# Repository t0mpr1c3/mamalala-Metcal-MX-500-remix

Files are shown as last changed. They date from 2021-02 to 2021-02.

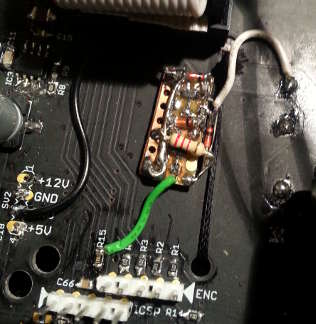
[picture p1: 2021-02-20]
doc/randomfunprojects build/build_undervoltage_lockout_PCB.jpg

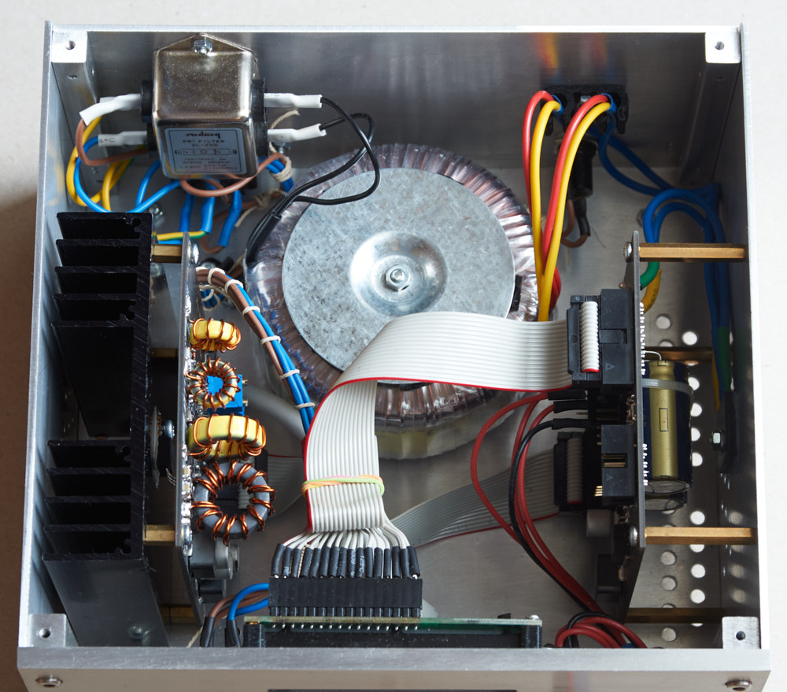
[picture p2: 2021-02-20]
doc/hww_build.jpg

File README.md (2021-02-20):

# Sources

This is the work of Christian Klippel (mamalala on EEVblog) in 2012-2013, with input from other users on the forum. This repository is an attempt to collate information punlished in the main project thread, https://www.eevblog.com/forum/projects/diy-metcal-13-56-mhz-rf-supply/

I haven't attempted to build the project myself and have no specialist knowledge to bring to bear.

## richard.cs build

http://randomfunprojects.co.uk/metcal.html

### Comment in post #374

"Whilst you could use the original gerbers I would suggest a few changes:
1) Add in pads for the extra 56 pF capacitor.
2) Put some thermal relief in. I've found a lot of areas where something that carries no real current (DC or RF) like a logic pulldown is unsolderable with a small iron because one end is hard-down onto a large area of ground plane.
3) Consider swapping the LCD pinout to the standard one.
4) A little bit of BOM rationalisation would be nice. For example the Aux supply capacitor for the switcher (can't remember the number now) is currently the only 1206 10nF in the design and could have been the same as the 10nF 0805's scattered everywhere.
5) Depending on your skill with surface mount soldering the pads might benefit from tweaking slightly - they're perfect for reflow but a little tight for hand work."

"The mounting holes on the board are 3.2 mm, this is a perfectly normal size for clearance M3 but I suspect that for many people with an electronics-only background getting four tapped holes in position to within perhaps 0.2 mm will be difficult, and being tapped the heatsink holes can't simply be opened out a little bigger. Might I suggest that loose-fitting 3.5 mm or even 4 mm holes might be preferable on a future board revision."

### Comment in post #375

"The mounting holes on the board are 3.2 mm, this is a perfectly normal size for clearance M3 but I suspect that for many people with an electronics-only background getting four tapped holes in position to within perhaps 0.2 mm will be difficult, and being tapped the heatsink holes can't simply be opened out a little bigger. Might I suggest that loose-fitting 3.5 mm or even 4 mm holes might be preferable on a future board revision."

### Comment in post #512

"I built [my toroids] as per the schematic and notes, with 1uH, 1uH, 400n, 11 turns on a T80, 14 turns on a T50 and then 10 on the next T50. It works well and I've made no attempt to optimise it further."

## See also

- https://hackaday.com/2019/06/16/homemade-magic-makes-the-metcal-go/
- https://habr.com/en/post/451246/
- https://github.com/SergeyMax/SolderingStation
- https://www.eevblog.com/forum/reviews/metcal-mx-5200-and-mx-5000-firmware-and-data-eeprom-information/

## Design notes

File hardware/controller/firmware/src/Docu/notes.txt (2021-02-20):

idle voltage around 14V
boost/limit around +/- 3.5V change in idle voltage

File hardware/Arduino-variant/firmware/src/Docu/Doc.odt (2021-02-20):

The encoder button has various uses:

- Single click

- Long push

- Double click

- Single click followed by a long push

Single click:

Press encoder button down and then quickly release it

Long push:

Press and hold down encoder button for a second or two

Double click:

Press encoder button, quickly release it, then immediately press and release it again

Click + longpush:

Press encoder button, quickly release it, then press it again and hold down for 1 or 2 seconds

During normal operation the LCD shows a status-icon in the top-left corner, depicting the current power setting (Off, Normal, Limit, Boost) and a „still alive“ animation in the bottom row of the icon. Next to the icon is the bargraph showing the current output power. In the bottom line the current power-manager state is shown, or alternatively the currently active power manager configuration name. Toggle between the two by double-clicking the encoder button.

Status Icons:

Power Output Off

Normal Power Output

Limited Power Output

Boosted Power Output

When in automatic mode, i.e. with the power manager enabled, the following actions are possible:

- Single click used to turn on/off

- When turned on, Click-Longpush to enter sleep mode when

- When in sleep mode, rotate the encoder to force wake up

- Longpush to enter the main menu

When in manual mode, i.e. with the power manager disabled, the following actions are possible:

- Single click to turn on/off, memorizes last power level for on

- Turn encoder left/right to change output power mode (Off, Normal, Limit, Boost)

- Longpush to enter main menu

Main Menu

From the default info-display after power-up, the main can be entered by a longpush on the encoder button. Push & hold the button until the main menu is displayed. Once in the main menu, rotate the encoder to select the desired option. These are:

- Main Setup: Global system configuration

- Edit Config: Edit the power-manager configuration

- Save Config: Save the edited power manager configuration

- Load Config: Load and activate one of the stored power manager configurations

- Show Version: Display the firmware name and version

- Reset: Reboot the firmware

To select a menu item, simply click the encoder button once.

To exit the main menu, simply do a longpush on the encoder button again until you are back to the main info display.

Main Setup

This configures the basic, global parameters of the system. Changes made here are immediately active. Rotate the encoder to cycle through the available options. These are:

- Language: Select the language used for display and serial output. Currently English and German are implemented.

- Baudrate: Set the baudrate of the serial interface. Only the baudrate can be selected, the other parameters for the serial port are always 8,N,1. Note: When realtime logging is used, a low baudrate will cause a very slow response of the system, so select a suitably high baudrate in this case.

- Logger: What info messages to log through the serial port, realtime parameter logging

- Startup PM Conf.: Select which power-manager configuration to automatically load at system power-up from the configuration storage.

When selection an option, the currently active one is displayed by default. To cahnge the option, simply rotate the encoder to select the desired one, and then do a single click which does the actual selection and in turn brings you back to the options overview. The Logger options are different since these are multiple-choice. A * in front of the selected option shows that it is active. Do a single click to toggle between active and non-active. Rotate the encoder to select a different sub-option. Do a longpush to get back to the options overview. The Startup PM Conf. option will show you the textual name of the selected config-set from memory.

When exiting the Main Setup options the selected settings will automatically be saved to the internal EEPROM.

Edit Config

This allows to edit the runtime parameters of the power-manager. Selecting this option will first bring up which parameterset to edit. The choices are:

- Current Config: The currently active configuration

- From Default Cfg: Start with a configuration filled with default parameters

- One of the eight stored configurations. The name of that config will be shown in the bottom line of the LCD, while the memory slot it used is displayed in the upper-right corner of the LCD, from #0 to #7

A single click will select the configuration and starts the editor, a longpush will exit and go back to the main menu. The options are grouped into sub-items as follows:

- Startup Mode:

- Auto, On – Auto, Off – Manual, On – Manual, Off

- Heatup Mode

- Normal Power – Power Limit – Power Boost

- Heatup End Cond.

- Timed – Pwr Lvl Thresh.

- Heatup End Param

- HeatupLim, Time – HeatupLim, PwrTh – HeatupBst, Time – HeatupBst, PwrTh

- Idle Parameters

- Idle Threshold – Enter Sleep Time

- Sleep Options

- Sleep Mode - Auto-Powerdown

- Sleep Mode Param

- Light Sleep Time – Light Slp Thresh – Sleep Threshold – Auto-Off Time

- Wakeup Mode

- Normal Power – Power Bosst

- Wakeup End Cond.

- Timed – Pwr Lvl Thresh.

- Wakeup End Param

- WakeupBst, Time – WakeupBst, PwrTh

- Normal Backlight

- Constant – Pulsing - Flashing

- Sleep Backlight

- Constant – Pulsing - Flashing

- Auto Off Backl.

- Constant – Pulsing - Flashing

- Const. BL Param.

- Const. BL. Level

- Pulse BL Param.

- Pulse Level Low – Pulse Level High – Pulse Speed

- Flash BL Param

- Flash Level Low – Flash Level High – Flash On-Time – Flash Off-Time

- Config Name

- Actual name of the currently edited parameter set

To select a group, click the selection. Then select which parameter to change and click again. Adjust the parameter as wanted and click or longpush. This will bring you back to the parameter selection of that group. To go back to the group selection then, do a longpush. To exit the editor, do another longpush.

The name editor is slightly different. When starting to edit the name, the current name will be shown in the top line on the LCD. In the bottom line a – is shown. Rotate the encoder to move that marker under the character that is to be changed. Then click the encoder button. The marker will change to a ^ and thus indicate that the character is to be changed. Rotate the encoder to change it. Click to get back to the – marker to select another character. The name-editing can be aborted by a longpush. To save the edited name, use a clickpush instead.

In case of multi-option (i.e. The Sleep Options), a single click will enable/disable the option, a longpush will go back to the option selection menu.

The option-groups and their parameters have the following purposes/meanings:

- Startup Mode: Select in which mode to start-up the unit after power-on/reset

- Auto, On: Automatic power management is enabled, turned on after power-up

- Auto, Off: Automatic power management is enabled, turned off after power-up

- Manual, On: Manual control mode, turned on after power-up

- Manual, Off: Manual control mode, turned off after power-up

- Heatup Mode: Select what power level to use for initial heatup

- Normal Power: Use normal power output during heatup

- Power Limit: Use limited power output during heatup

- Power Boost: Use boosted power output during heatup

- Heatup End Cond.: Select the condition to end initial heatup, only for boost/limit heatup modes

- Timed: End heatup phase after a given number of seconds

- Pwr Lvl Thresh.: End heatup phase when power output fall below a given threshold

- Heatup End Param: Times (in seconds) and power levels for the limit/boost heatup modes

- HeatupLim, Time: Time after which to end the limited power heatup phase

- HeatupLim, PwrTh: Power level below which to end the limited power heatup phase

- HeatupBst, Time: Time after which to end the bossted power heatup phase

- HeatupBst, PwrTh: Power level below which to end the boosted power heatup phase

- Idle Parameters: Defines threshold between idle/heating mode, and a time after which to enter sleep mode

- Idle Threshold: Rise in output power after which to go from idle to heating mode

- Enter Sleep Time: Time in seconds of idling after which to go to sleep mode, if enabled

- Sleep Options: Enable/disable the sleep-mode and automatic power-down

- Sleep Mode: Enable/disable the entering of the sleep mode when idling too long

- Auto-Powerdown: Enable/disable the auto-powerdown mode when sleeping too long

- Sleep Mode Param: Define times and thresholds for the sleep mode

- Light Sleep Time: Time spent in ininital sleep mode, to accomodate power level change from idle mode

- Light Slp Thresh: Rise threshold in output power when in inital sleep mode, wakes up when exceeded

- Sleep Threshold: Rise threshold in output power for normal sleep mode, wakes up when exceeded

- Auto-Off Time: Time spent sleeping after which to automatically power down

- Wakeup Mode: Power output setting when waking up from sleep mode

- Normal Power: Wake up using normal power output

- Power Boost: Wake up with boosted output power (quicker thermal recovery)

- Wakeup End Cond.: Condition to end boosted output power wakeup, when enabled

- Timed: End boosted power wakeup after given time in seconds

- Pwr Lvl Thresh.: End boosted output power wakeup when power consumption falls below a given threshold

- Wakeup End Param: Time (in seconds) and power level for the boost wakeup modes

- WakeupBst, Time: Time after which to end the bossted power wakeup phase

- WakeupBst, PwrTh: Power level below which to end the boosted power wakeup phase

- Normal Backlight: Which LCD Backlight mode to use to signal normal operation (heatup, idle, etc.)

- Constant: Fixed brightness level

- Pulsing: Fade brightness level up/down continously

- Flashing: Flash brightness level

- Sleep Backlight: Which LCD Backlight mode to use to signal sleep mode

- Constant: Fixed brightness level

- Pulsing: Fade brightness level up/down continously

- Flashing: Flash brightness level

- Auto Off Backl.: Which LCD Backlight mode to use to signal automatic power down mode

- Constant: Fixed brightness level

- Pulsing: Fade brightness level up/down continously

- Flashing: Flash brightness level

- Const. BL Param.: Brightness level used for constant backlight

- Const. BL. Level

- Pulse BL Param.: Brightness levels and time/speed for pulsating backlight

- Pulse Level Low: Minimum brightness to fade from/to

- Pulse Level High: Maximum brightness to fade from/to

- Pulse Speed: Speed to fade between low/high brightness, bigger=slower and smaller=faster

- Flash BL Param: Brightness levels and times/speeds for flashing backlight

- Flash Level Low: Minimum brightness to quickly fade to

- Flash Level High: Maximum brightness to flash to

- Flash On-Time: Time spent for high-brightness flash-fade

- Flash Off-Time: Time spent to wait for next flash

- Config Name

- Actual name of the currently edited parameter set

Save Config

This allows to save the edited runtime parameters of the power-manager. Selecting this option will first bring up which parameterset to load. The choices are:

- Make Active: Activate the currently edited configuration, i.e. ese it. No actual saving is done.

- One of the eight stored configurations. The name of the config currently present in the selected slot will be shown in the bottom line of the LCD, while the memory slot it used is displayed in the upper-right corner of the LCD, from #0 to #7. Click to select that slot and overwrite it with the edited config.

Load Config

This allows to load and activate the runtime parameters of the power-manager. Selecting this option will first bring up which parameterset to load. The choices are:

- From Edit Config: The currently edited configuration

- One of the eight stored configurations. The name of that config will be shown in the bottom line of the LCD, while the memory slot it used is displayed in the upper-right corner of the LCD, from #0 to #7

Show Version

This will show the firmware name and version. Simply rotate the encoder to exit from that display.

Reset

Do a reboot of the firmware, same result as if power-cycling the unit.

The config editor always allows to edit all options, no matter if they depend on another config option or not. For example, the Heatup End Cond and Heatup End Param are only used when either the limited power or the boosted power heatup mode is selected, but never used when the normal heatup mode is chosen.

When editing a config, it is just that: an edited config. It does not become active unless it is either saved to EEPROM and then loaded, or when explicitely chosen to activate it.

EEPROM storage uses CRC checksums to verify that all is OK. When an invalid CRC is encountered, the config or parameter set will be replaced with a default one. This applies to both, the main config as well as any of the power manager configurations. When flashing the firmware into the µC it will create default configurations at the first power up. This is also shown in the ourput on the serial interface. Default serial port speed is 115200 Baud.

The encoder handling has a very crude „dynamic“ in it. The faster it is turned, the bigger the steps in which it changes. This allows to adjust a large value range without needing to rotate it for ages. However, it is just that: crude. So donÄt expect too much from it.

Button handling is not perfect either. Sometimes it just misses something. Especially when extensive realtime logging is enabled on the serial port. That extensive logging then also affects the rotary encoder.

The menu handling and config editor „run“ in the background, depending on which one is active. That means that the power manager is always running. So you can happily edit something or stay in the menu without affecting the automatic power management.

Multi-language support in the firmware is implemented by using a big array of pointers to strings, one for each language. The active array is the selected by the language manager, depending on the chosen language. To access a string, a simple tr() macro is defined which takes the string-index and returns the pointer to that string in program memory.

The actual strings are defined in strings_EN for English, and strings_DE for German. In language_strings.h is a long list of defined string names that represent the index to a string. The order of these #defines must be the same as the strings in the actual strings_* files. In the same include files the number of languages etc. are defined at the top.

To add a new language simply create a new strings_* file, use the strings_EN as a template here. Replace all the strings to whatever language you want. Change the NUM_LANGUAGES accordingly, and add a new „#define LANG_*“ to languages_strings.h. Then extend the language_entries[] struct in languages_strings.c, and add the „#include strings_*“ for the new language to it. That should be all....

All the menu and config option stuff is defined in their own structs, so that the main handlers stay the same while allowing to easily add new menus, sub-menus, options, etc.

Not much documentation in the source code yet. After all, this is just V00.01, that is, the first somewhat usable revision.

There are quite some leftovers in the files from the development. Stuff has changed, but some code not deleted or #defines removed. In short: it's quite a mess right now. Also, some names used for functions, variables and defines are not that good and should change.

Have fun!

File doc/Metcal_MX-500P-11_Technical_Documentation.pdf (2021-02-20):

# METCAL MX-500P-11 TECHNICAL DOCUMENTATION

This documentation was carefully reverse engineered from several actual MX-500P units, and although it has been meticulously triple checked, it may contain errors and omissions so use it at your own risk. It is provided solely for the purpose of helping you satisfy your personal curiosity about how a Metcal MX-500P works, and you must never use it for any other purpose, especially not for any commercial or business purpose, and certainly not as an aide to experimenting with or performing work on MX-500P units, as it is inadequate for such unintended use. Reproduction is strictly forbidden.

MECHANICAL DESCRIPTION:

The small plastic cover at the two RF output connectors is held in place by it's two plastic hooked clips which descend into the aluminum housing at the top and bottom. Beneath this plastic cover are two hex nuts that bolt the RF connectors to the aluminum housing. The RF connectors are soldered directly into the circuit board. On the rear of the MX-500P are four deeply recessed T15 tamper proof Torx screws which hold the two halves of the aluminum casting together. Loosening the single screw in the upper-middle back of the MX-500P by a few turns releases the internal heat sink which is attached to the circuit board. The internal heat sink couples heat into the MX-500P aluminum case from where it can dissipate into the ambient air. Good thermal coupling between the internal heat sink and the case is aided by a thin coating of white thermal compound. The circuit board inside the MX-500P is fastened down by six internal screws, four of which are rather large because they also hold down the line transformer. The tiny grub screw on the upper right hand side of the MX500 controls the Auto Sleep feature and should not be tightened past the point where it gently activates the switch. Note that it can be dangerous to power up an MX-500P unit that has been taken apart or that has been reassembled by anyone other than an trained Metcal service technician.

DESCRIPTION OF FUNCTION:

The MX-500P Power Unit provides RF energy at 13.560MHz to the Soldering Tip Cartridge, which contains an induction heater consisting of an 18 turn AWG33 wire coil wound around a 0.11" diameter by 0.5" long slug. The slug is composed of a copper core, clad in a thin magnetic alloy having a curie point equal to the desired soldering tip temperature. The magnetic alloy absorbs RF energy from the coil, causing the slug to heat up until the curie temperature is reached. At this point absorption stops and heating ceases, because the RF energy is now reflected back to the power unit by the copper core.

The On/Off switch atop the power unit controls the 18V power supply U8, which runs all the supervisory circuits. When the 18V supply is off, Q6 turns off thereby causing Q7 to turn on and disable the RF generator.

Q5 and Q8 control a small DC bias voltage out to the soldering hand piece, so that U2a can sense an intermittent or disconnected hand piece cable, in which case the yellow LED DS2 will light and U2b will latch Q7 on, thereby disabling the RF generator until the On/Off switch is cycled.

U5a senses small changes in RF generator output power to the soldering hand piece. If no changes are detected for half an hour then sleep mode timer U6 times out causing U7 to latch Q11 on, thereby disabling the RF generator until the On/Off switch is cycled. This functionality can be disabled by backing out the tiny grub screw in the upper right side of the unit.

If thermal switch TS1 detects an over temperature condition inside the power unit then Q9 will turn on and disable the RF generator until the temperature drops back down to normal.

If Forward Power at T3 and C33 exceeds reasonable limits due to a fault in the power unit circuitry, then Q19 will turn on and disable the RF generator until Forward Power returns to acceptable levels.

U5b monitors the supervisory circuits and lights green LED DS1 if everything is OK, in which case Q12 will be on, enabling U4 to power up the RF generator.

U1 provides a 13.560MHz square wave out to class C driver stage Q3, which in turn drives the class C final output stage Q4, providing RF power to the soldering hand piece. Note that Q3 is unusual in that it has an input capacitance of only 55pF and a gate threshold voltage of only 1.6V.

Diodes D8 and D9 sense the RF voltage level coming out of the RF generator, providing negative feedback to switching power supply U4 Q1 Q2, which powers the final RF output stage Q4 of the RF generator.

J1 provides a DC voltage which is proportional to the power being delivered to the hand piece. It can be connected to an analog meter movement or other measuring instrument.

TRIMPOT DESCRIPTIONS:

RV2 adjusts the RF-Output-Power delivered to the hand piece; if this adjustment is incorrect then the voltage at C8 will likely not correspond to the values given elsewhere in this document.

RV1 sets the Forward-Power-Fault safety shutdown circuit trip point; if this adjustment is incorrect then the voltage at C16 will likely not correspond to the values given elsewhere in this document.

RV3 calibrates the signal out to any Meter connected at J4; the signal at J4 is not normally used so it is hard to imagine how this adjustment could have any impact upon the operation of the unit.

Calibration is well beyond the scope of this document and must not be attempted by anyone other than a qualified Metcal service technician.

MEASUREMENTS FROM SOME GOOD WORKING UNITS:

Whenever unit is plugged into the AC line:
Voltage at C2 will measure approximately 26 VDC
Voltage at C6 will measure approximately 53 VDC Whenever the power switch is on and unit is plugged in:
U8 pin 3 will measure 18 VDC
U7 pin 14 will measure 12 VDC
Whenever a hand piece is connected and the green LED is lit: U4 pin 4 will measure 1.3 VDC
U4 pin 5 will measure 0.0 VDC
If the green LED is extinguished but the unit is plugged in: U4 pin 5 will measure 26 VDC
Whenever the hand piece is idling hot in the stand:
Voltage at C8 will measure between 17 and 18 VDC Voltage at C3 will measure between 14 and 15 VDC
Voltage at C16 will measure approximately minus 1.2 VDC
U1 pin 14 will measure approximately 4.8 VDC
U1 pin 4 will have a 13.56 Mhz waveform approximately 2.8 Vpp When the soldering hand piece is heating up from a cold start:
Voltage at C8 may temporarily rise as high as 21 VDC
Voltage at C16 may temporarily rise as high as minus 0.22 VDC When the hot hand piece is touched to something cold:
U5 Pin 1 will pulse high momentarily
Characteristics of a cold MX Soldering Tip Cartridge:
Inductance at 1kHz is somewhere around 2.8 uH DC resistance is fairly close to 0.21 ohms

ADDITIONAL INFORMATION:

For specifications and descriptions of operator controls and lights, please consult you Metcal Users Manual and the 1999 Metcal product catalog which can be found on the Internet via Google as of this writing.

US Patent Number 4626767 contains a wealth of additional technical information. US Patents are available for free on the Internet from various sources such as http://www.freepatentsonline.com/

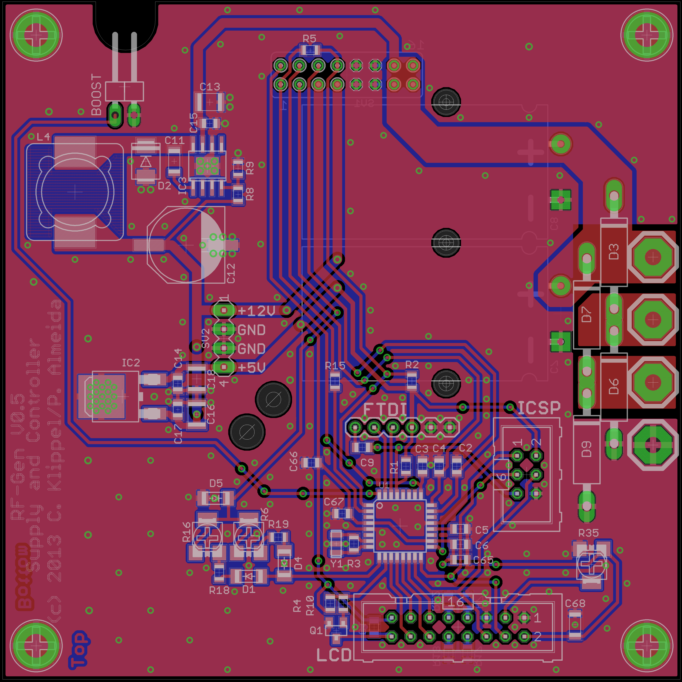
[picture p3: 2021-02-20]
hardware/Arduino-variant/ControllerBoard.png

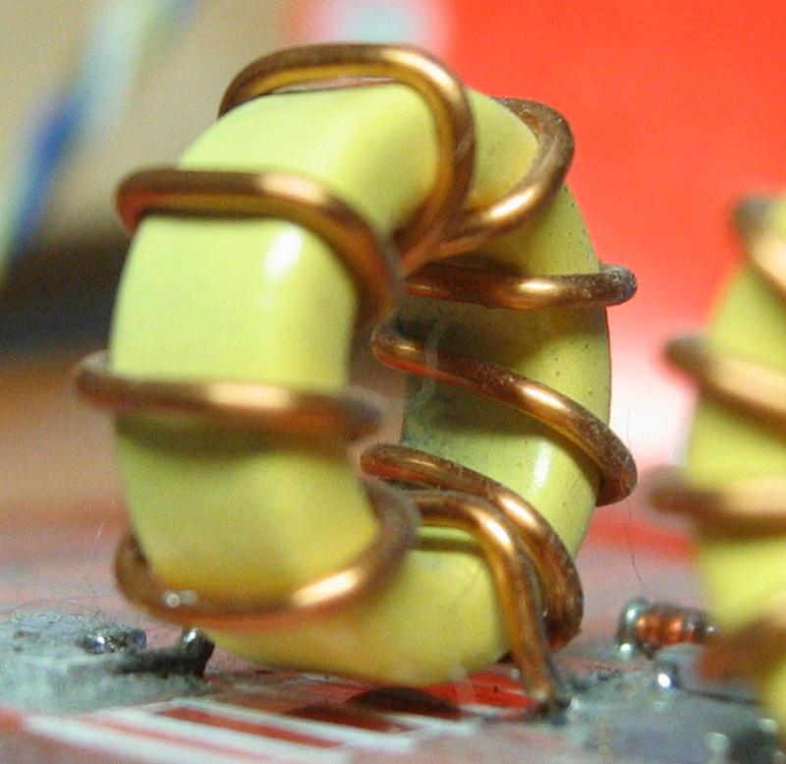
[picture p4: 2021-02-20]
doc/coil_4.jpg

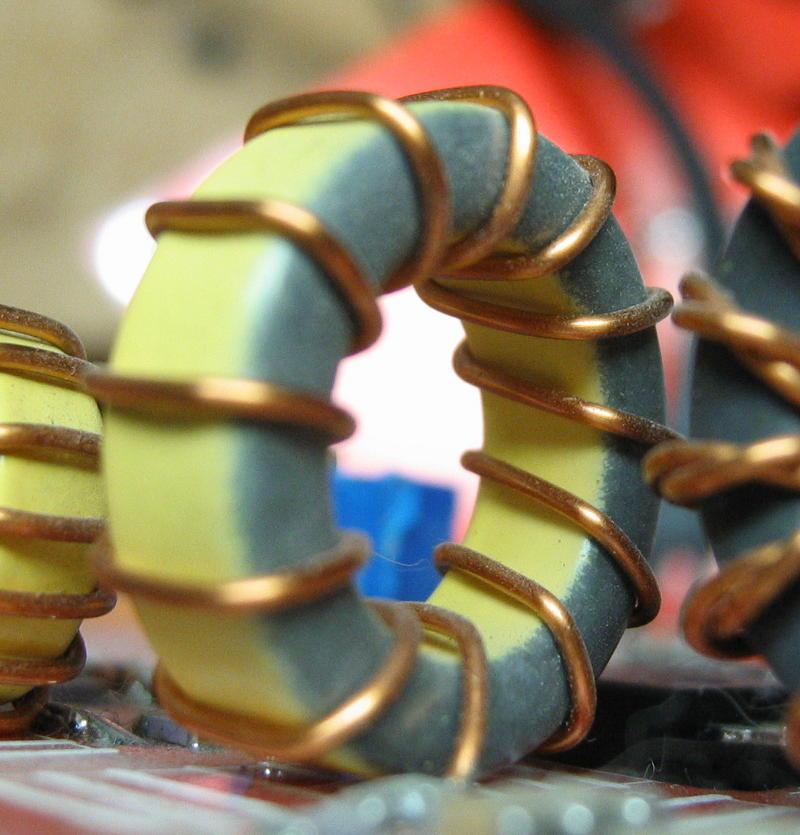
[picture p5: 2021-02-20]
doc/coil_2.jpg

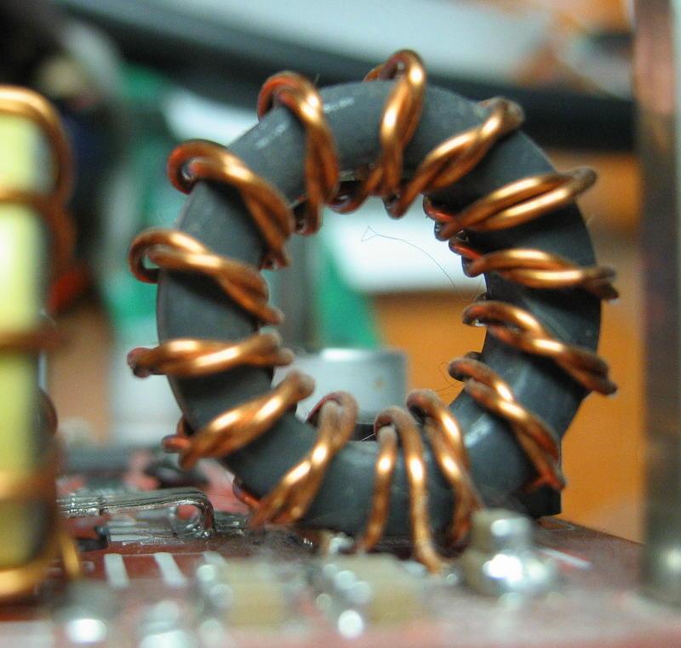
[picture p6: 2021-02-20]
doc/coil_1.jpg

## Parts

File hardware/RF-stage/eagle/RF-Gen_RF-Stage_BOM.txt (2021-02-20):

Partlist exported from C:/Users/Tom/Documents/hack/metcal/MX-500P/mamalala-Metcal-MX-500-remix/hardware/RF-stage/eagle/RF-Gen_RF-Stage.sch at 2/20/2021 10:58 AM

Part  Value                     Device              Package          Description       
C1    100µ/50V                  C-POL-EU-AL_100_108 CAP_AL_100_108                     
C2    10µ/50V                   C-EU-1210           C_1210_REFLOW                      
C3    10µ/50V                   C-EU-1210           C_1210_REFLOW                      
C4    10µ/50V                   C-EU-1210           C_1210_REFLOW                      
C5    100n                      C-EU-0805           C_0805_REFLOW                      
C6    10n                       C-EU-1206           C_1206_REFLOW                      
C7    100µ/50V                  C-POL-EU-AL_100_108 CAP_AL_100_108                     
C8    100µ/50V                  C-POL-EU-AL_100_108 CAP_AL_100_108                     
C9    100n                      C-EU-0805           C_0805_REFLOW                      
C10   100n                      C-EU-0805           C_0805_REFLOW                      
C11   100n                      C-EU-0805           C_0805_REFLOW                      
C12   4µ7                       C-EU-1206           C_1206_REFLOW                      
C13   100n                      C-EU-1206           C_1206_REFLOW                      
C14   47n                       C-EU-1206           C_1206_REFLOW                      
C15   47n                       C-EU-1206           C_1206_REFLOW                      
C16   47n                       C-EU-1206           C_1206_REFLOW                      
C17   47n                       C-EU-1206           C_1206_REFLOW                      
C18   47n                       C-EU-1206           C_1206_REFLOW                      
C19   47n                       C-EU-1206           C_1206_REFLOW                      
C20   22p                       C-EU-1206           C_1206_REFLOW                      
C21   22p                       C-EU-1206           C_1206_REFLOW                      
C22   56p                       C-EU-1206           C_1206_REFLOW                      
C23   56p                       C-EU-1206           C_1206_REFLOW                      
C24   56p                       C-EU-1206           C_1206_REFLOW                      
C25   56p                       C-EU-1206           C_1206_REFLOW                      
C26   56p                       C-EU-1206           C_1206_REFLOW                      
C27   56p                       C-EU-1206           C_1206_REFLOW                      
C28   56p                       C-EU-1206           C_1206_REFLOW                      
C29   56p                       C-EU-1206           C_1206_REFLOW                      
C30   56p                       C-EU-1206           C_1206_REFLOW                      
C31   56p                       C-EU-1206           C_1206_REFLOW                      
C32   56p                       C-EU-1206           C_1206_REFLOW                      
C33   100n                      C-EU-0805           C_0805_REFLOW                      
C34   100n                      C-EU-0805           C_0805_REFLOW                      
C35   10n                       C-EU-0805           C_0805_REFLOW                      
C36   10n                       C-EU-0805           C_0805_REFLOW                      
C37   56p                       C-EU-1206           C_1206_REFLOW                      
C38   56P                       C-EU-1206           C_1206_REFLOW                      
C39   56p                       C-EU-1206           C_1206_REFLOW                      
C40   N/A                       C-EU-0805           C_0805_REFLOW                      
C41   2µ2                       C-EU-1206           C_1206_REFLOW                      
C42   100n                      C-EU-0805           C_0805_REFLOW                      
C43   100n                      C-EU-0805           C_0805_REFLOW                      
C44   22p                       C-EU-0805           C_0805_REFLOW                      
C45   22p                       C-EU-0805           C_0805_REFLOW                      
C46   100n                      C-EU-1206           C_1206_REFLOW                      
C47   100n                      C-EU-1206           C_1206_REFLOW                      
C48   56p                       C-EU-1206           C_1206_REFLOW                      
D1                              DIODE-SMB           SMB              RECTIFIER DIODES  
D2    1N4148                    DIODE-LL-34         LL-34            RECTIFIER DIODES  
D3    1N4148                    DIODE-LL-34         LL-34            RECTIFIER DIODES  
D4    Z5.6                      DIODE-LL-34         LL-34            RECTIFIER DIODES  
D5    Z5.6                      DIODE-LL-34         LL-34            RECTIFIER DIODES  
D6    1N4148                    DIODE-LL-34         LL-34            RECTIFIER DIODES  
D7    1N4148                    DIODE-LL-34         LL-34            RECTIFIER DIODES  
D8    Z5.6                      DIODE-LL-34         LL-34            RECTIFIER DIODES  
D9    z5.6                      DIODE-LL-34         LL-34            RECTIFIER DIODES  
D10   Z5.6                      DIODE-LL-34         LL-34            RECTIFIER DIODES  
FET1  IRF510                    NFETTO22_INPCB      TO220_INPCB                        
IC1   LM22676TJ7A               LM22676TJ7A         TO-263_THIN                        
IC2   ISL55110TSSOP-8           ISL55110TSSOP-8     TSSOP-8                            
IC3   TLV2374                   TLV2374SOIC-14      SOIC14                             
IC4   SN74LVC1GX04DBV           SN74LVC1GX04DBV     DBV-R-PDSO-G6                      
L1    22µ                       L-EU-SSR1260        SSR1260                            
L2    22µ                       L-EU-SSR1260        SSR1260                            
L3    11 turns T80-6            L-EU-T80_U          L_T80_U                            
L4    14 turns T50-6            L-EU-T50_U          L_T50_U                            
L5    8 turns T50-6             L-EU-T50_U2         L_T50_U2                           
L6    47µ                       L-EU-2424           L_2424                             
PAD1                            SMDPAD5X4           SMDPAD_5X4                         
PAD2                            SMDPAD5X4           SMDPAD_5X4                         
Q1    2N7002                    BSS123              SOT23            N-CHANNEL MOS FET 
Q2    2N7002                    BSS123              SOT23            N-CHANNEL MOS FET 
R1    22k                       R-EU-0805           R_0805_REFLOW                      
R2    18k                       R-EU-0805           R_0805_REFLOW                      
R3    2k2                       R-EU-0805           R_0805_REFLOW                      
R4    1k                        R-EU-0805           R_0805_REFLOW                      
R5    2M                        R-EU-0805           R_0805_REFLOW                      
R6    1k                        R-EU-0805           R_0805_REFLOW                      
R7    22k                       R-EU-0805           R_0805_REFLOW                      
R8    4R7                       R-EU-1206           R_1206_REFLOW                      
R9    4R7                       R-EU-1206           R_1206_REFLOW                      
R10   22k                       R-EU-0805           R_0805_REFLOW                      
R11   100                       R-EU-0805           R_0805_REFLOW                      
R12   100                       R-EU-0805           R_0805_REFLOW                      
R13   100                       R-EU-0805           R_0805_REFLOW                      
R14   100                       R-EU-0805           R_0805_REFLOW                      
R15   22k                       R-EU-0805           R_0805_REFLOW                      
R16   100                       R-EU-0805           R_0805_REFLOW                      
R17   22k                       R-EU-0805           R_0805_REFLOW                      
R18   82k                       R-EU-0805           R_0805_REFLOW                      
R19   5k                        TRIM_EU-S64Y_SMD    S64Y_SMD         POTENTIOMETER     
R20   100                       R-EU-0805           R_0805_REFLOW                      
R21   1k                        R-EU-0805           R_0805_REFLOW                      
R22   22k                       R-EU-0805           R_0805_REFLOW                      
R23   22k                       R-EU-0805           R_0805_REFLOW                      
R24   100                       R-EU-0805           R_0805_REFLOW                      
R25   5k                        TRIM_EU-S64Y_SMD    S64Y_SMD         POTENTIOMETER     
R26   4k7                       R-EU-0805           R_0805_REFLOW                      
R27   1k                        R-EU-0805           R_0805_REFLOW                      
R28   1k                        R-EU-0805           R_0805_REFLOW                      
R29   1k                        R-EU-0805           R_0805_REFLOW                      
R30   1k                        R-EU-0805           R_0805_REFLOW                      
R31   22k                       R-EU-0805           R_0805_REFLOW                      
R32   2k                        TRIM_EU-3364W       3364W            POTENTIOMETER     
R33   100                       R-EU-0805           R_0805_REFLOW                      
R34   100                       R-EU-0805           R_0805_REFLOW                      
SV1                             MA08-2SMD           MA08-2-SMD       PIN HEADER        
U$1   MOUNTPADM3_WASHER         MOUNTPADM3_WASHER   PAD_M3_WASHER                      
U$2   MOUNTPADM3_WASHER         MOUNTPADM3_WASHER   PAD_M3_WASHER                      
U$3   MOUNTPADM3_WASHER         MOUNTPADM3_WASHER   PAD_M3_WASHER                      
U$4   MOUNTPADM3_WASHER         MOUNTPADM3_WASHER   PAD_M3_WASHER                      
XFMR1 2 x 13 o. 14 Turn FT82-61 XFMR_1_1_CTT80_U    XFMR_T80_U                         
XTAL1 13.56MHz                  XTALSMD_5.0X3.2     XTAL_SMD_5.0X3.2

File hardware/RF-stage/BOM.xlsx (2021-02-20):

QUANTITY | PART | VALUE | PACKAGE | MFG N° (EXAMPLE) There are other and maybe cheaper alternatives | HARD TO GET BITS INCL.
 | RESISTORS 1%
7 | R4,R6,R21,R27,R28,R29,R30 | 1K | 0805 | CRCW08051K00FKEA
8 | R1,R7,R10,R15,R17,R22,R23,R31 | 22K | 0805 | CRCW080522K0FKEA
8 | R11,R12,R13,R14,R16,R20,R33,R34 | 100R | 0805 | CRCW0805100RFKEA
1 | R24 | 200R | 0805 | CRCW0805200RFKEA
1 | R5 | 2M | 0805 | CRCW08052M00FKEA
1 | R3 | 2.2K | 0805 | CRCW08052K20FKEA
2 | R8,R9 | 4.7R | 1206 | CRCW12064R70JNEA
1 | R26 | 4.7K | 0805 | CRCW08054K70FKEA
1 | R2 | 18K | 0805 | CRCW080518K0FKEA
1 | R18 | 160K | 0805 | CRCW0805160KFKEA
 | TRIMPOTS
1 | R32 | 2K | TRIM3364W | 3364W-1-202E
1 | R19, R25 (omitted) | 5K | (Bend pins to fit SMD) 3296Y | 3296Y-1-502LF
 | NOT INSTALLED
1 | Non-inductive dummy load (use with big heatsink) | 50R | TO-247 | MHP100500F
QUANTITY | DIODE
4 | D2,D3,D6,D7 | LL4148 | SOD80 / LL34 | FDLL4148
1 | D1 | 5A | DO214AA / SMB | CDBB560-HF
5 | D4,D5,D8,D9,D10 | 5.6V | SOD-80C / LL34 | BZV55-C5V6
QUANTITY | CAPACITORS
3 | C1,C7,C8 | 100uF/50V or 63V | PANASONIC FK | EEEFK1H101P or EEEFK1J101P
3 | C2,C3,C4 | 10uF/50V | 1210 X7R | GRM32ER71H106KA12L
8 | C5,C9,C10,C11,C33,C34,C42,C43 | 100nF | 0805 X7R | GRM21BR71H104KA01L
1 | C6 | 10nF | 1206 X7R | GRJ31BR72J103KWJ1L
1 | C12 | 4.7uF/25V | 1206 X7R | GRM31CR71E475KA88L
3 | C13,C46,C47 | 100nF/250V | 1206 X7R | GRM31CR72E104KW03L
6 | C14,C15,C16,C17,C18,C19 | 47nF | 1206 X7R | GRJ31CR72E473KWJ3L
1 | C20 (omitted),C21 | 22pF | 1206 C0G/NP0 | GRM31A5C2J220JW01D
14 | C22,C23,C24,C25,C26,C27,C28,C29,C30 (omitted),C31,C32,C37,C38,C39,C48 | 56pF | 1206 C0G/NP0 | GRM3165C1H560JZ01D
2 | C35,C36 | 10nF | 0805 C0G/NP0 | GRM2195C1H103JA01D
1 | C41 | 2.2uF/16V | 1206 X7R | GRM31MR71C225KA35L
2 | C44,C45 | 10pF | 0805 C0G/NP0 | GRM21A5C2E100JW01D
 | NOT INSTALLED
 | C40 | - | - | -
QUANTITY | INDUCTORS
2 | L1,L2 | 22uH | DR127 | DR127-220-R
1 | L3 -DIY- | 11 turns | T 80-6 | AMIDON T 80-6 | X
1 | L4 -DIY- | 14 turns | T 50-6 | AMIDON T50-6 | X
1 | L5 -DIY- | 8 turns | T 50-6 | AMIDON T50-6 | X
1 | L6 | 47uH | PIS2408 | FASTRON L-PIS2408 | X
1 | XFMR1 DIY |  | FT 82-61 | Ferritring 5961000601 | X
 | Copper Enamel Wire |  |  | sold by 10m Spool if needed
QUANTITY | IC /ACTIVE
1 | IC1 | LM22676 | TO-263 DDPAK | LM22676TJE-ADJ/NOPB
1 | IC2 | ISL55110 | TSSOP-8 | ISL55110IVZ
1 | IC3 | TLV2374 | SOIC-14 | TLV2374ID
1 | IC4 | SN74LVC1GX04DBV | SOT-23 | SN74LVC1GX04DBVT
1 | XTAL1 | 13.56MHZ OSC | 7B | 7B-13.560MEEQ-T
2 | Q1,Q2 | 2N7002 | SOT-23-3 | 2N7002,215
QUANTITY | MECHANICAL
1 | SV1 | 2x8 | 0.1" pitch pin header

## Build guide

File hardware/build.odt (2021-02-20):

13.56 MHz RF Power Supply

RF Generator Board

Notes, Assembly and Adjustment

© 2012 Christian Klippel <c.klippel@gmx.de>

This document describes the basic operation principle, assembly steps and required adjustment for a 13.56 MHz RF power supply. Such a supply can be used with soldering handpieces, cartridges, tweezers, etc. from the OKI/Metcal and Thermaltronics soldering systems designed to operate at this frequency.

With this project you should be able to build your own power supply unit for these systems. Please note that this is not a direct copy of the existing power supply designs. While it is based on the same principles, the design itself was created from ground up by myself. There are quite some differences in this design compared to the existing ones, mainly in an attempt to hopefully make the whole circuitry simpler.

The supply is basically a RF generator at a fixed frequency, 13.56 MHz in this case, where the feedback loop of the DC supply of the final stage includes the actual RF output/reflected measurement to ensure that the output stage is not damaged when a mismatch occurs. The cartridges work by RF induction into a special alloy which, at a fixed temperature, loses its ability to have energy induced magnetically. When that Curie point is reached, a mismatch of the RF load (the cartridge) will occur, and most of the RF energy is reflected back into the output stage. With fixed-power output stages this would lead to the destruction of the output stage. However, in these units here the RF power is reduced as soon as the mismatch occurs to prevent this from happening.

IC1 on this board is the DC/DC buck converter that provides the DC voltage to the output stage. Between L4 and L5 the peak voltage of the RF signal is picked up by the circuitry on the lower-left on page 3 of the circuit diagrams. That circuitry is just a simple peak detector. It's output is buffered by one of IC3's op amps, and then fed back, through a series resistor, into the feedback pin of IC1. So what this combination does is effectively trying to provide a constant peak voltage at the junction between L4 and L5. At power up pretty much all the RF energy is consumed by the tip cartridge. Once it reaches its design temperature, that RF energy is reflected back into the supply. This will lead to an increasing peak voltage seen by the peak-detector. In the end, the output of the op amp rises as well, causing a higher voltage at IC1's feedback input. This in turn will cause IC1 to decrease its output voltage, and thus the voltage seen by the peak detector: the feedback loop is complete.

Another important part of the circuit is the detection of the tip cartridge. This is accomplished by the circuitry in the lower-right of page 3 of the circuit diagrams. The tip cartridge has a very low DC resistance. This part of the circuit sends a small DC current through the tip, which will effectively pull the gate of Q1 to ground, thus Q1 is switched off. If the tip is removed Q1 is now switched on by the pullup resistor R21. Basically, L6 blocks the RF AC voltage, whereas R20 and C41 provide a low-pass filter that adds a tiny delay to debounce the resulting signal.

A useful extra in this circuit is the SWR bridge. This provides a detection of the forward and reflected RF energies which in turn can be evaluated by external circuitry to provide finer control of the system. However, this part is somewhat optional and not required for the basic operation of the supply.

The circuit is designed to include some failsafe and protection points. For example, I included a bunch of 5.6 V Zener diodes. Normally they would do nothing. But in case something fails, they should provide some basic protection against overvoltage at the inputs of the parts on the 5 V rail, mainly the op amp and whatever circuitry follows that.

Another difference to the original units is the driver part of the output FET. While the originals use another FET as driver, I decided to use the ISL55110 FET driver chip from Intersil. It is a tiny chip, designed to drive a FET with sufficient current, at high frequencies. I also created a much smaller and simpler oscillator circuit. The originals, at least the older ones, use a full 7404 chip and crystal to form the oscillator. However, there is the SN74LVC1GX04 available from Texas Instruments, which is basically just a '04, but condensed down into a small SOT23-6 package and internally wired for operation as an oscillator. To this I connected a small 5.0 x 3.2 mm SMD 13.56 MHz crystal, plus the required feedback and series resistor, as well as the load capacitances for the crystal.

Generally I tried to use parts that are easy to solder by hand. Passives are not smaller than 0805, for example. As for the part values and tolerances, for some parts it is important to have the exact same specs that I will give in the part lists, for others there is quite some leeway. For example the voltage rating of the bulk capacitor at the input of the DC/DC buck converter. This obviously depends on what you decide to use to power it with. I used 50 V spec'd stuff there, just to be on the safe side. But you are welcome to change that, if you must.

I will mark the important parts with a *, to indicate that the specs of those parts are important. I will also add some commentary about what parts are optional. For example, if you don't need the SWR bridge stuff, you can leave those parts out. However, in that case a low-Ohm resistor should be connected between the op amp inputs and GND instead of the small capacitors.

Considering this, I will not give a single, complete part list for the whole board. Instead I will provide partial part lists with each section that will be explained in the instructions below, together with some comments on those parts.

Alright then, so let's start building it!

To build and test this circuit you need a few tools at hand. One is a suitable power supply. The values I give in this document refer to +30 V for the DC input to the buck converter. You also need a +5 V and +12 V supply for the op amp, oscillator and FET driver.

There are a few toroids that need to be wound with magnet wire (that is, enameled copper wire) between 0.7 and 0.8 mm in diameter.

A normal multimeter should be OK to successfully build this circuit, but having a scope available surely won't hurt in case something does not work out as expected.

You also need a 50 Ohm, non-inductive dummy load. It should be a 50 Watts type, one of these things that is used by radio hams, for example. This we will use to provide a basic load to the buck converter during assembly, as well as load to the RF output later on.

You need a decent soldering iron with tips suitable for SMD soldering, plus a larger hoof tip to solder the buck regulator thermal pad to the PCB.

And of course the usual tools like pliers, etc.

The first section to assemble is the DC/DC buck converter section as seen in the graphic below.

Part # | Value | Size | Notes
C1, C7, C8 | 100µ / 50V* | 10.0 x 10.8 mm | Low-ESR electrolytic
C2, C3, C4 | 10µ / 50V* | SMD 1210 | X7R, at least C2, others optional
C5 | 100n / 50V* | SMD 0805 | X7R
C6 | 10n / 50V* | SMD 1206 | X7R
R1 | 22K | SMD 0805 | Pulldown, 22K minimum
R2 | 18K* | SMD 0805 | 1% or better
R3 | 2K2* | SMD 0805 | 1% or better
R4 | 2K* | SMD 0805
R11 | 4K7 | SMD 0805 | Can be omitted, see text
R32 | 2K* | SMD 3364W | Or any other that fits footprint
D1 | 60V / 5A | SMB | Schottky, for example SK56B R4
L1, L2 | 22µ*, 4A min. | SSR1260 | Or any other that fits footprint SSR1260-220M from Bourns for example
IC1 | LM22676* | TJ7A | TO-263 thin package
SV1 | 2 x 8* | 0.1” | SMD pin- or socket-header, see text

In this section we have one optional part. This is resistor R11. If you want your controller to be able to temporarily increase or decrease the output voltage, you need to install this resistor here. The value of 4.7 K is just a rough guide, it actually depends on how you control this functionality later on (that is, what voltage levels you inject and how).

What gender the connector SV1 has is up to you. You can use a pin header here and plug a flat-ribbon cable plus connector onto it, or you can use a socket header and plug in the controlling board into that, in case you want to stack the two boards. The reason to use a socket header (female) in case of a stacked configuration is because you can get long THT pin headers, but not long socket headers.

The very first part to solder in is IC1, using a large hoof tip. This is because we need to solder its thermal pad as well, and other parts would be in the way otherwise. First we need to fill the vias on the PCB in the area that the thermal pad should be soldered to. Also we tin the thermal pad of IC1 a bit. Here are two images of the areas of interest, one before and one after tinning/filling:

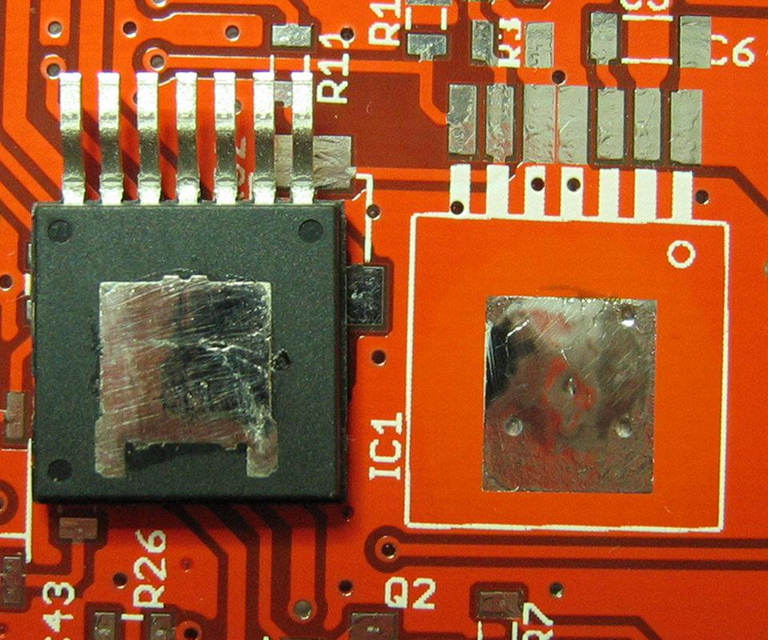
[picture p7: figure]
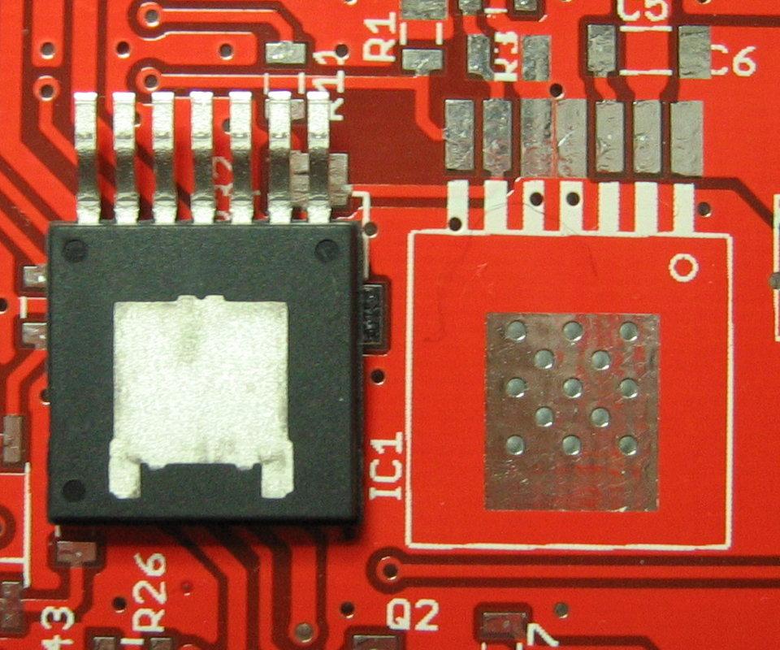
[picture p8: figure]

Add enough solder to the area on the PCB so that it slightly bulges, then clean off the flux residues on the PCB and the chip. The idea here is that when the chip is placed, it will be slightly tilted when from the side. We also tack-on the chip at the two outermost pins:

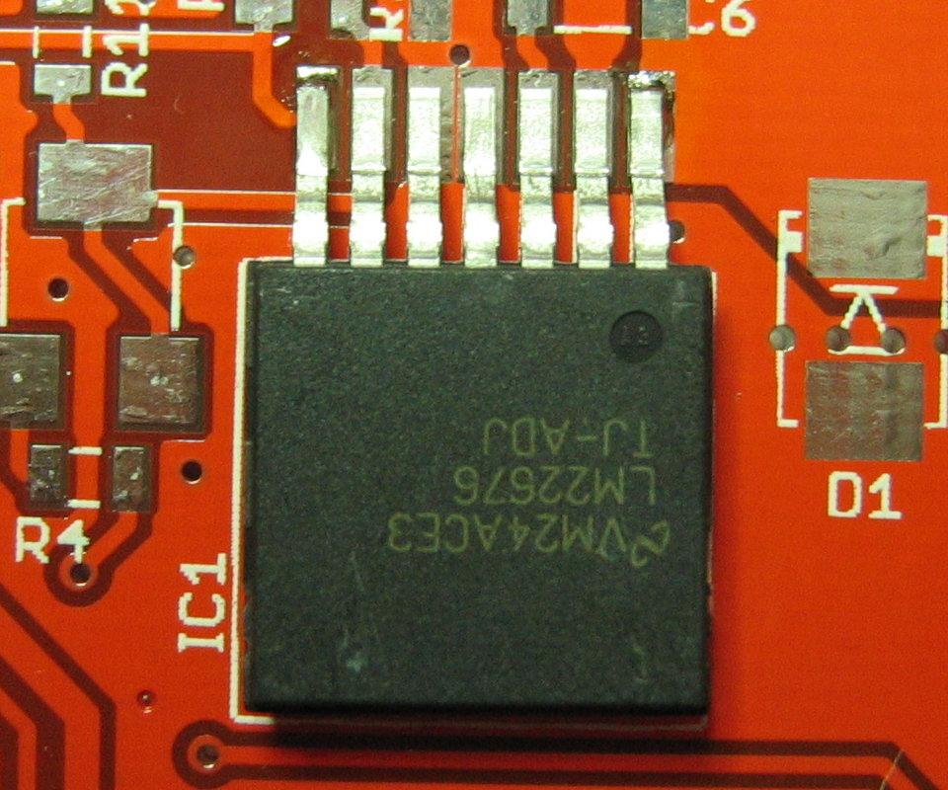
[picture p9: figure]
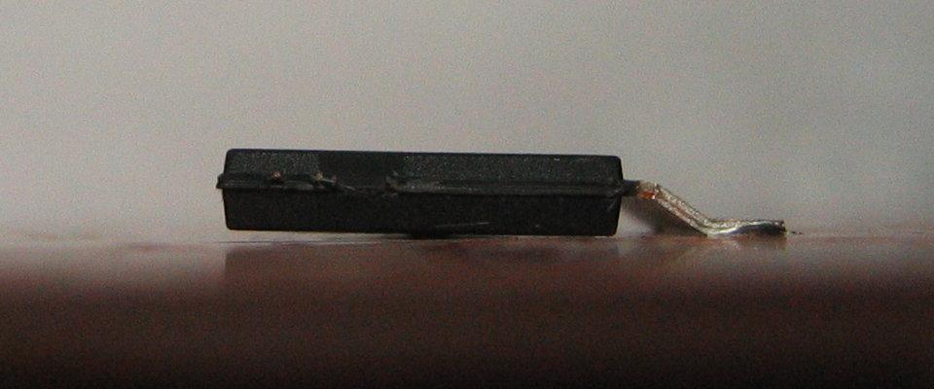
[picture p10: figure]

Now flip over the PCB, preferably on a hard surface. Add plenty of solder to the area where the thermal vias are. Now apply pressure with your fingers, above and below that area. With the other hand put the hoof tip into the tinned area. Move the tip around over the whole area for a while. The idea is that the vias, filled with solder, will conduct the heat to the other side and melt the solder there. Due to the applied pressure it will then solder IC1 flat on, giving a good thermal contact between its thermal pad and the copper of the PCB. Check from the side that the chip is really flat on. If needed repeat the procedure. Ance all is OK, use some desolder wick and remove excess solder, so that you have virtually no bulging in that area anymore. Then clean off the flux residues, flip the board over again and solder on the remaining pins:

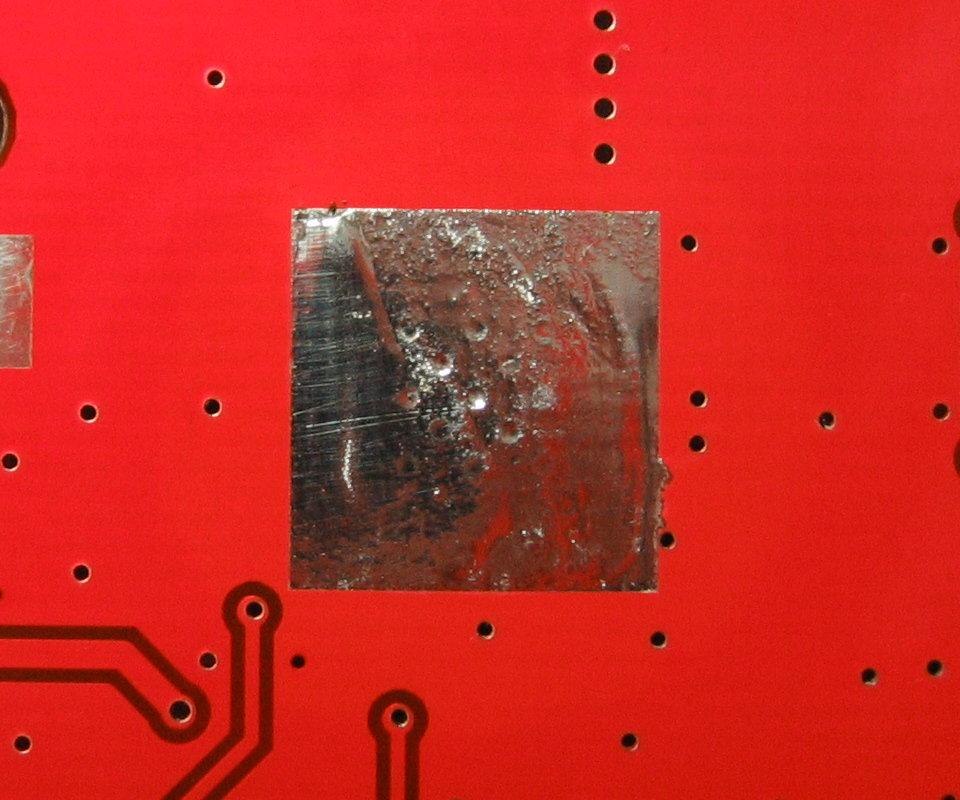
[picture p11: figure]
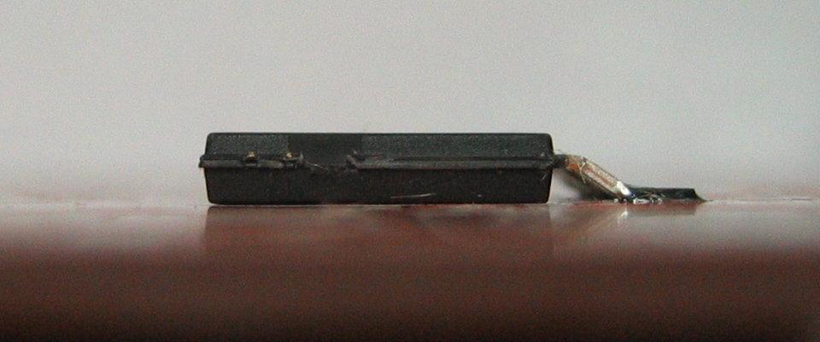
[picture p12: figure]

Now solder in the remaining parts, L1 and L2 first because their pads would be hard to reach later on. Add C7 and C8 next. Now all the small SMD passives around IC1, followed by C1. Finally solder the connector SV1 in place.

Now it's time for the first test. You need a +30 V and a +5 V supply, as well as the 50 Ohm dummy load. Connect the dummy load between the output side of L2 (which goes into XFMR1) and GND. For that you can temporarily solder it to the GND pad of FET1 and the proper pad of XFMR1. Solder some temporary wiring to the following pads of SV1: 10/12 for GND, 14/16 for +30 V and 1 for +5 V. First apply the +30 V and measure at the output of L2. There should be no voltage, since IC1's enable pin is pulled low. Now apply +5 V to pin 1 of SV1. This will enable IC1, and you should see around 11.7 V at the output of L2. Leave the dummy load connected for now, we need it again in the next step.

If all that works out OK the next section can be assembled. If not, recheck your solder work, the part values, etc.

The next section is the op amp and its surroundings, shown in the image below:

Part # | Value | Size | Notes
C42 | 100n / 16V | SMD 0805
C43 | 100n / 16V | SMD 0805 | Optional, see text
C36 | 10n / 16V | SMD 0805 | Optional, see text
R23 | 22K* | SMD 0805 | See text
R24 | 22K* | SMD 0805
R33, R34 | 100R | SMD 0805 | Alternatively R25, see text
R25 | 5K* | S64Y | Alternatively R33/R34, see text
R26 | 4K7* | SMD 0805 | Optional, see text
R27 | 1K* | SMD 0805 | Optional, see text
R28, R29, R30 | 1K | SMD 0805 | Optional, see text
R16 | 100R | SMD 0805 | Optional, see text
R17 | 22K | SMD 0805 | Optional, see text
R19 | 5K* | S64Y
D4, D5, D10 | Zener 5.6V* | LL34 | Optional, see text
IC3 | TLV2374 | SOIC-14 | Or any other rail-to-rail capable op amp

This section is mainly for the RF energy feedback loop of IC1, but also for buffering the forward/reflected RF energy levels coming from the SWR bridge, as well as providing an output voltage proportional to the buck converters output, to be used by some external circuitry if wanted.

At a bare minimum IC3, R19, R23, R24, C42 and either the combination R33/R34 or the trimpot R25 are needed. These parts generate the feedback voltage that is fed into the buck converter in accordance with the peak detectors output. The op amp used in this stage has a voltage offset defined by R33/R34 or R25. Usually half the supply voltage of IC3 is OK, as provided with R34/R35. But if you want to play around a bit with the feedback loops behaviour, go for the adjustable version using R25 instead.

The trimpots used are multiturn, and normally THT parts. To make them SMD parts just bend out the pins accordingly, and shorten them. R23/R24 define the gain of this stage. If you want to experiment you can tweak these values to get a more or less aggressive regulation.

R26/R27 are a voltage divider to sense the output of the buck converter. It is smoothed a bit by C43, and limited to 5.6 V by Zener D10. This section is optional. It is useful if you want to detect load changes, or generally want to have that info available to the controller circuit. R28 decouples the output a bit in case of capacitive loads there. If you place a 100n capacitor to GND on the controller board there, it will provide a small low-pass filtering to give a more stable reading.

R16/R17/C36/D5 precondition the signal of the reflected RF energy as detected by the SWR bridge. R30 is again at the output of the op amp for the same reasons as R28 is.

If you do not want the voltage reading and/or the SWR functionality, terminate the then unused op amp inputs to GND. You can do that by replacing C43 with a low-Ohm resistor for the voltage reading, and doing the same with C36 for the reflected output of the SWR bridge, and C35 from the next section for the forward output of the bridge.

Once you have soldered in all the parts for this section, turn R19 fully counter-clockwise and in case you use R25, adjust it to the middle position (that is, when powered by +5 V it should give you 2.5 V output at the center pin). Now apply the +30 V again, as described in the previous section, and at the same time apply +5 V to pins 1 and 5 of SV1.

Now adjust the trimpot R32, next to IC1, so that you get about 22 V at the output of L2. This sets the maximum possible output voltage that IC1 can generate, except for the case where you externally feed in some voltage level through the optional R11 described in the previous section. If all works fine, continue with the next section.

This section will provide the RF peak detector, plus some parts of the SWR bridge. Again, here is an image of the parts used in this section:

Part # | Value | Size | Notes
C37, C38, C39 | 56p / 500V* | SMD 1206 | C0G, ceramics
C33 | 100n / 16V | SMD 0805 | Optional, see text
C35 | 10n / 16V | SMD 0805 | Optional, see text
R13, R14 | 100R* | SMD 0805 | Optional, see text
R15 | 22K | SMD 0805 | Optional, see text
R18 | 160K* | SMD 0805
D8 | Zener 5.6V* | LL34
D6, D7 | LL4148* | LL34 | Simple 1N4148 diode in SMD
D2 | LL4148 | LL34 | Optional, see text

All the non-optional parts form the peak detector. The optional parts are for the forward detection of the SWR bridge.

The 56p/500V caps are the same that will be used in the output filter section later on.

Nothing to test here, so just recheck that everything soldered correctly and proceed to the next section.

This section contains the tip-detection circuitry, as well as a few parts for the optional SWR bridge. These are the parts in question:

Part # | Value | Size | Notes
L6 | 47µ | SMD 2424 | Can be bigger in value. Current handling of only a few mA, and whatever footprint fits.
C40 | | | Not used, ignore
C41 | 2µ2 / 16V | SMD 1206 | Can be bigger in value
C34 | 100n / 16V | SMD 0805 | Optional, see text
R20 | 100R | SMD 0805
R21 | 1k | SMD 0805
R22 | 22k | SMD 0805
R12 | 100R | SMD 0805 | Optional, see text
D3 | LL4148 | LL34 | Optional, see text
D9 | Zener 5.6V* | LL34
Q1 | 2N7002 | SOT23-3 | Or equivalent

The tip-detection is implemented by sending a small DC current through the tip. Since the tip has a very low DC resistance, this will effectively pull the gate of Q1 to GND, turning it off. L6 filters out the RF AC voltage of the RF output, while R20 and C41 provide a low-pass filter. If no tip is connected, R21 pulls the gate of Q1 high, turning it on.

R12/C34/D3 are part of the SWR bridge for the reflected power detection. These can be omitted if you do not want that feature.

To test the tip detection connect a LED plus suitable current limiting resistor between pin 5 (+5V) and pin 8 (tip detection output, open drain to GND) of SV1. Apply +5V to pin 5 (and GND on either of the pins 9, 10, 11, 12 of SV1). The LED should now light up. Shorten the two pads of the RF output, the LED should now turn off.

If things work out as wanted, proceed with the next section.

Now it's time to assemble the section that provides the 13.56 MHz oscillator and the FET driver chip. As usual, here is an image of that section:

Part # | Value | Size | Notes
C44, C45 | 10p | SMD 0805 | Load capacitors for the crystal
C9, C10, C11 | 100n / 16V | SMD 0805 | Decoupling
C12 | 4µ7 / 16V | SMD 1206 | Can be bigger in value
R5 | 2M* | SMD 0805
R6 | 1K* | SMD 0805
R7, R10, R31 | 22K | SMD 0805
R8, R9 | 10R | SMD 1206
Q2 | 2N7002 | SOT23-3 | Or equivalent
IC4 | SN74LVC1GX04 | SOT32-6 (DBV) | Texas Instruments
IC2 | ISL55110 | TSSOP-8 | Intersil
XTAL1 | 13.56 MHz | SMD 5.0 x 3.3 mm | e.g. 7B-13.560MEEQ-T

This is a basic oscillator circuit, nothing special. It provides the 13.56 MHz signal. The ISL55110 is used as the driver for the FET output stage. Be aware that there is the 55111 as well. That one, however, has one output inverted. So make sure to get the proper one.

Unfortunately the enable/power-down signal of the driver has inverted polarity to what the buck converter uses. For that reason this signal is inverted by R7, R31 and Q2.

R8/R9 are in series between the driver outputs and the FET gate. This limits the current used to drive the FET and also spreads the load over the two outputs that the ISL provides. R10 is a safeguard that turns off the output FET in case IC2 fails. It does not, however, prevent havoc if IC2 fails with the outputs high.

R5 is the feedback resistance needed by the oscillator chip IC4, R6 is a limiting resistor to not overdrive the crystal. C44 and C45 provide the load capacitance of the crystal. 10pF is the suggested value, but if in doubt check the specs of the crystal you want to use.

Testing this section requires a scope or at least a frequency counter. Provide +5 V to SV1 pins 1 and 5, and +12 V to SV1 pin 7. The 12 V are used by the driver. Of course don't forget GND. You should see the 13.56 MHz at R8/R9, as well as pins 3 and 4 of the driver.

Since the driver is so small, but has to deliver quite some current (albeit only for rather short spikes), it would be a good idea to provide at least a minimal thermal coupling to the PCB. Unfortunately this package does not have a thermal pad. You’ll want to place a small dab of non-conductive thermal compound at the place where IC2 is located. Don't use too much compound, it should not squeeze out onto the pads when you push down the chip to solder it in place.

Alright, now that this is done we go to the next section, the RF output filter.

Now the second last section, RF output transformer and filter. And of course again an image of that section:

Part # | Value | Size | Notes
C13, C46, C47 | 100n* / 250V* | SMD 1206 | X7R*
C14-C19 | 47n* / 250V* | SMD 1206 | X7R*
C20, C21 | 22p* / 500V* | SMD 1206 | C0G*
C22-C32 | 56p* / 500V* | SMD 1206 | C0G*
XFMR1 | 2 x 13 turns* | FT82-61* | Amidon ferrite toroid, bifilar wound, 80 cm magnet wire 0.7 to 0.8 mm diameter
L3 | 1 x 11 turns* | T80-6* | Amidon iron powder toroid, 35 cm magnet wire 0.7 to 0.8 mm diameter
L4 | 1 x 14 turns* | T50-6* | Amidon iron powder toroid, 30 cm magnet wire 0.7 to 0.8 mm diameter
L5 | 1 x 10 turns* | T50-6* | Amidon iron powder toroid, 25 cm magnet wire 0.7 to 0.8 mm diameter

Now let's start by winding the output transformer and the filter coils onto the toroids. This is a bit nasty, since the coreas are rather small, and if you are unused to this kind of work it will be quite a strain on your fingers.

First we will wind the output transformer. It has a bifilar winding of 13 turns (which actually makes it two windings of 13 turns each). For this you need about 80 cm of magnet wire with 0.7 to 0.8 mm diameter. Stretch the wire a bit to even out any kinks it may have. Now fold it in the middle. Next is to twist these two strands. You should aim for 2-3 twists per cm. It is important that it is really twisted, and not one wire wound around the straight other. Here is an image of how the twisting should look like:

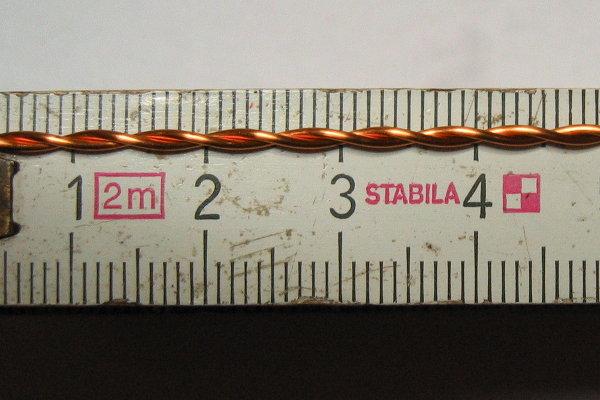
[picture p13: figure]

Now take the FT82-61 ferrite core and place a first, tight winding on it, like this:

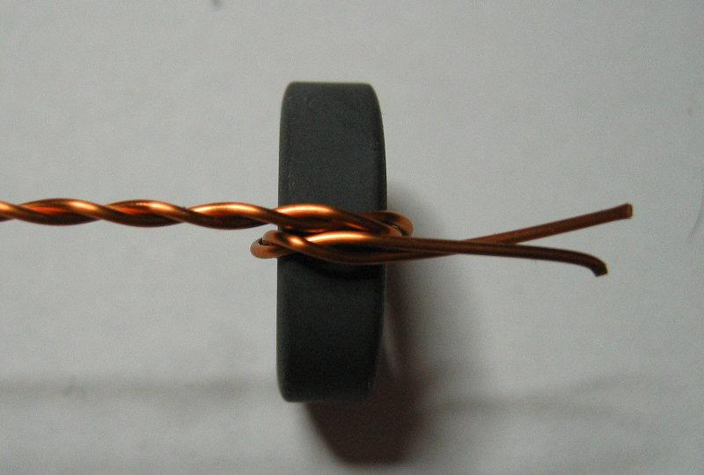
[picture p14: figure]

Next place the toroid between your thumb and index finger, so that your fingers are placed on the outer rim and the center of the core is open, with the thumb pressing the first turn against the toroid. Now thread the longer end of the twisted wire through the opening of the core and firmly pull on it to have it tightly wound around the core. Rotate the core a bit so that your thumb is now placed onto the new winding.

Repeat these steps until you have placed 13 turns onto the core. Try to have them roughly even-spaced. Bend the ends of the wire so that they go straight down. On the outer rim you should now count 13 turns. You can move around the winding a bit to get them more evenly spaced. The end result should look like this:

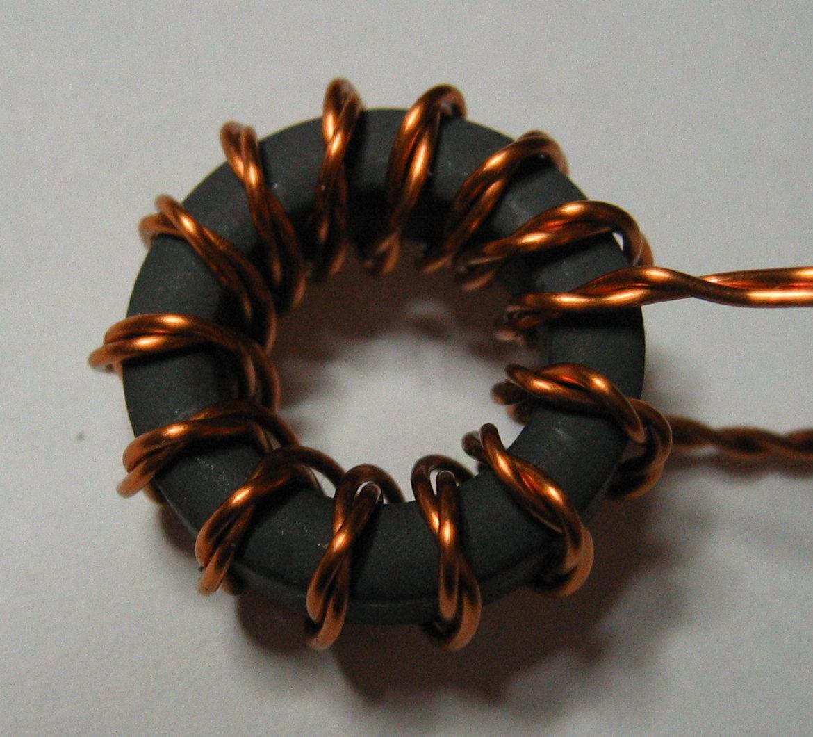
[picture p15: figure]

Now cut the longer end to the same length as the smaller end, and untwist both up to the toroid. Remove the isolation at the last 5 or 10 mm of the wire ends, it's ok to have it removed on only one side of the wire, no need yet to remove it all around.

Take a multimeter and find out which ends belong to which winding. The end of one winding needs to be twisted together with the beginning of the second one, this will become the center-tap. Here is an image where i have placed some markers:

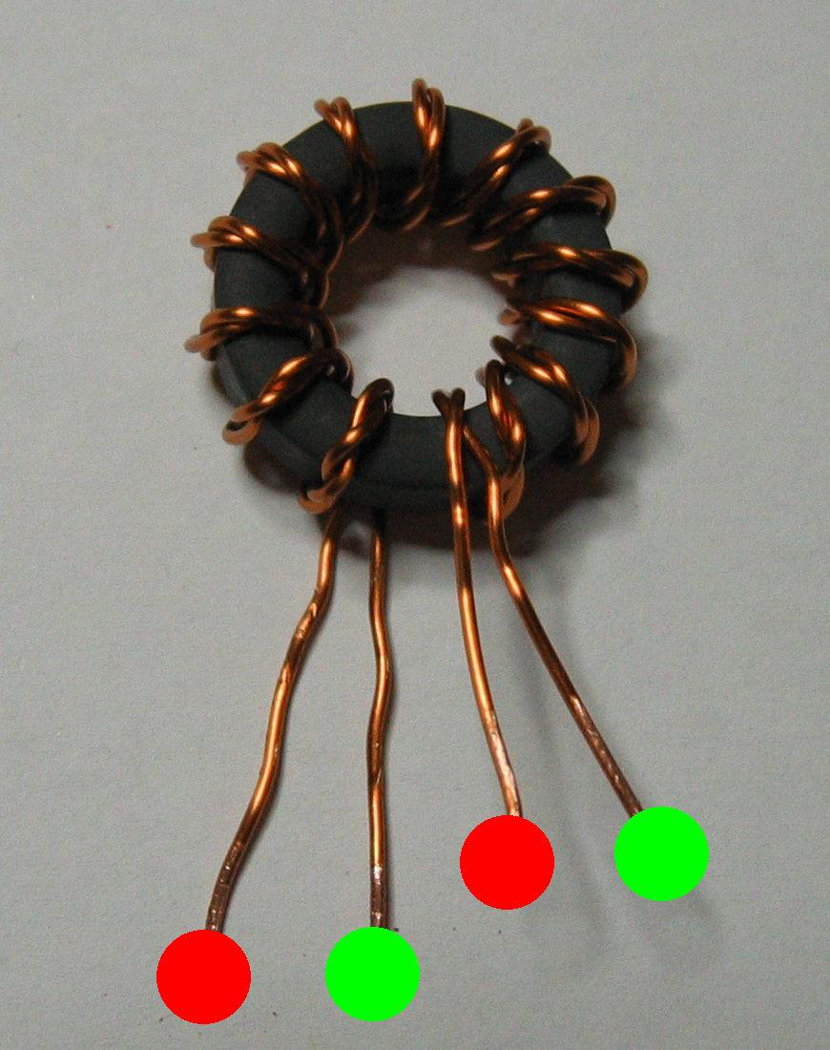
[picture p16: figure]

The leftmost wire from the bottom is the start of one winding, it's end on the leftmost side of the top. Same with the second winding. This is the arrangement you should prepare. You may need to untwist one end half a turn, chances are 50:50 to get it right on spot with the first measurement ;)

Now bend the beginning of the second winding (green dot on the left) and end of the second (red dot on the right) upward, and the end of the first winding (green dot on the right) downward. Remove the insulation of these four wires all around now. I use a sharp knife to do so. The result should look like this when viewed from the bottom:

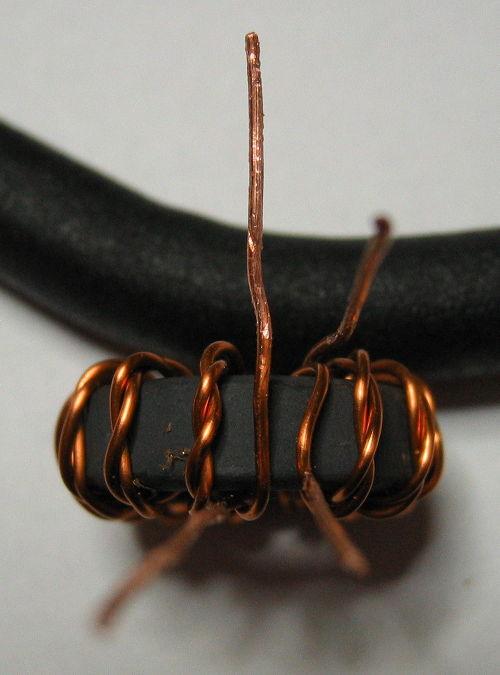
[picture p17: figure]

Twist together the upper two wires. Then tin the twisted pair as well as the other two single wires. Cut them to the proper length, and bend them in the required way. You should now end up with something that looks like this:

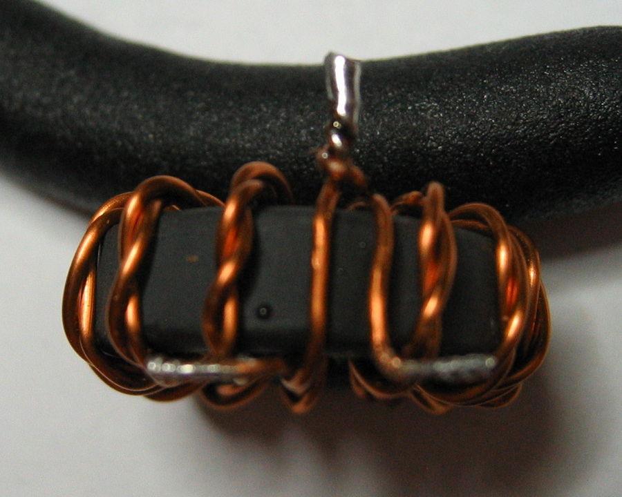
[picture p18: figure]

Next the filter coils are wound onto their toroids. The winding method is the same as for the transformer, only that a single wire is used now instead of a twisted one.

L3 has 11 turns on the T80-6 toroid. This means you should end up with counting 13 windings on the outer rim of the core. L4 is 14 turns on a T50-6 toroid, and L5 is 10 turns on another T50-6 toroid. Again, remove the insulation at the ends, tin them and bend them in the proper way.

Here is an image of how these toroids should look like in the end, From left to right is L3, L4 and L5:

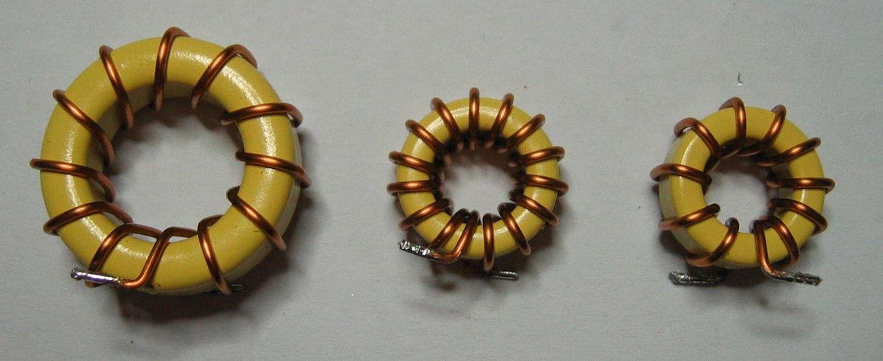
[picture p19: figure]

Here is another shot showing the coils from the bottom:

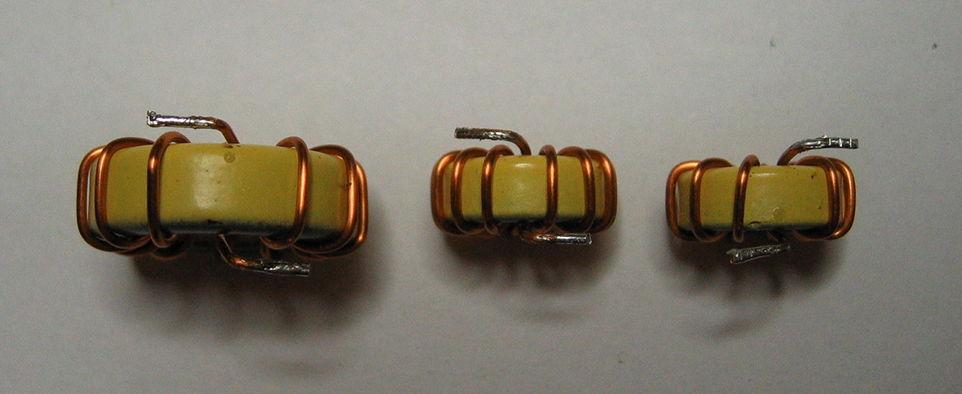
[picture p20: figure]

Now that the transformer and the coils are ready this section can be soldered. Start by soldering in the capacitors first. In the part list I mentioned that two of the capacitors are omitted. That would be C20 and C30. Just leave them out. Then solder in the transformer and the coils. If the wires are a bit too long simply shorten them. If they are too short, start over with the coils ;)

The coils and the transformer should probably be glued down with some dabs of epoxy glue or similar. You don't really need to if you don't plan on moving the unit around or dropping it. However, if they are not glued down you risk tearing them off in case of a shock or lots of vibration.

Now to the final part of the assembly, putting in the IRF510 FET. The original idea was to mount the whole PCB flat centered onto a 100 mm x 100 mm heatsink. So that is what I describe here.

Drill 2.5 mm holes at the proper places in the heatsink and cut 3 mm threads into them. If, like me, you don't really trust the long-term stability of the solder-stop, you may want to use some very thin adhesive film and stick that over the few traces that exists on the bottom side of the PCB. Alternatively you could also use a heat-transfer pad over the whole area. In that case you don't need to use the mica disc, thermal compound and isolating washer to mount the FET.

Now mount the PCB onto the heatsink, but first put a dab of thermal compound where the buck regulator and FET driver is (if you don't use the transfer-pad, that is). What you use to mount it depends on what you want to use to control it. You can use simple M3 screws, or use 25 mm long hex standoffs in case you want to build it sandwich-like, as I did. Those standoffs have an outer thread on one end, and an inner thread on the other. If you plan to use my supply/controller board design and place the bulk capacitors there at the bottom side, use 30 mm long standoffs instead.

Now shorten the legs of the FET about 2 mm, and bend the ends downward a bit. The pins are to be soldered onto the pads onto the PCB, with the FET itself placed in the square opening. Add a thin layer of thermal compound on the exposed part of the heatsink in that square. Put a mica disk for a TO220 package there. Then add a thin film of thermal compound on the backside of the FET. Put it in place and put an isolating washer, used to mount TO220 packages, into the FET's mounting hole. Now screw it down tightly with a M3 screw. Solder the pins onto their respective pads.

Next step is doing the adjustment of the output stage. To do so connect the 50 Ohm dummy load to the RF output. The dummy load really must be non-inductive. You can not use a big wire-wound resistor for this! It should be able to handle up to 50 watts for a while. If you don't have access to a suitable dummy load, for example through a friend who is into CB or ham radio, you have to build one yourself. Just search the net, there are plenty of instructions on how to cheaply make such a dummy load.

Now you need to apply all three voltages at once onto SV1. +5 V to pin 5, +12 V to pin 7, GND to pins 9, 10, 11 and 12, and +30 V to pins 13, 14, 15 and 16. The 5 V rail only needs a few mA, it only drives the oscillator, the input side of the driver, the op amp, voltage divider and some pull-up resistors. The 12 V rail needs a few hundred mA, since it is used by the driver to drive the FET. For the +30 V you need a few amperes, but not more than 3 A total. Apply these voltages at once, but leave pin 1 of SV1 unconnected.

A word of caution: Voltages well in excess of 100 volts will appear in the output filter stage, and at the RF output it will go over 100 volts as well. Be very careful here!

Verify that all the voltages are OK. Turn R19 to all the way clockwise until the end. Now connect pin 1 of SV1 to +5 V. This will now enable the buck regulator and the driver. A few hundred milliamperes should be drawn on the +30 V rail now. Adjust R19 counter-clockwise so that the output voltage at L2, which goes into XFMR1, comes up to about 21 V.

If you can not reach that point, you have to check and double check that all the soldering is OK, that you used the right parts in the right places, that the coils and the transformer are wound correctly, and that they are soldered well to the board. Also check that the FET is OK and not damaged (for example accidentally due to static discharge). A scope will be helpful to check the various stages from oscillator to RF output.

If everything works, congratulations! You now have a usable RF power supply. Switch off all the DC power supplies and disconnect the dummy load from the RF output. Instead connect a F type socket at the output, using a short length of RG58 coax cable between the RF output pads on the PCB and the F type socket. If you want just a basic supply with no fancy stuff added, connect pin 8 of SV1 to pin 1 of the same connector. Also add a pullup to +5 V of no more than 1k to pin 8. This is for the tip detection and will disable the driver and buck regulator when no cartridge is connected. It will automatically re-enable them once a cartridge is inserted.

That's it. Connect your handpiece or tweezers, or whatever suitable, to the F type socket. Insert the cartridge you want and turn it on. After a few seconds you are ready to solder. Of course it can't hurt to put the whole thing into a metal enclosure. Make sure it is well shielded!

The follow up part on all this will be about the supply/controller board i designed for this unit. However, that one is optional, you can use whatever you want to control this board and generate the required voltages.

Have fun,

Chris

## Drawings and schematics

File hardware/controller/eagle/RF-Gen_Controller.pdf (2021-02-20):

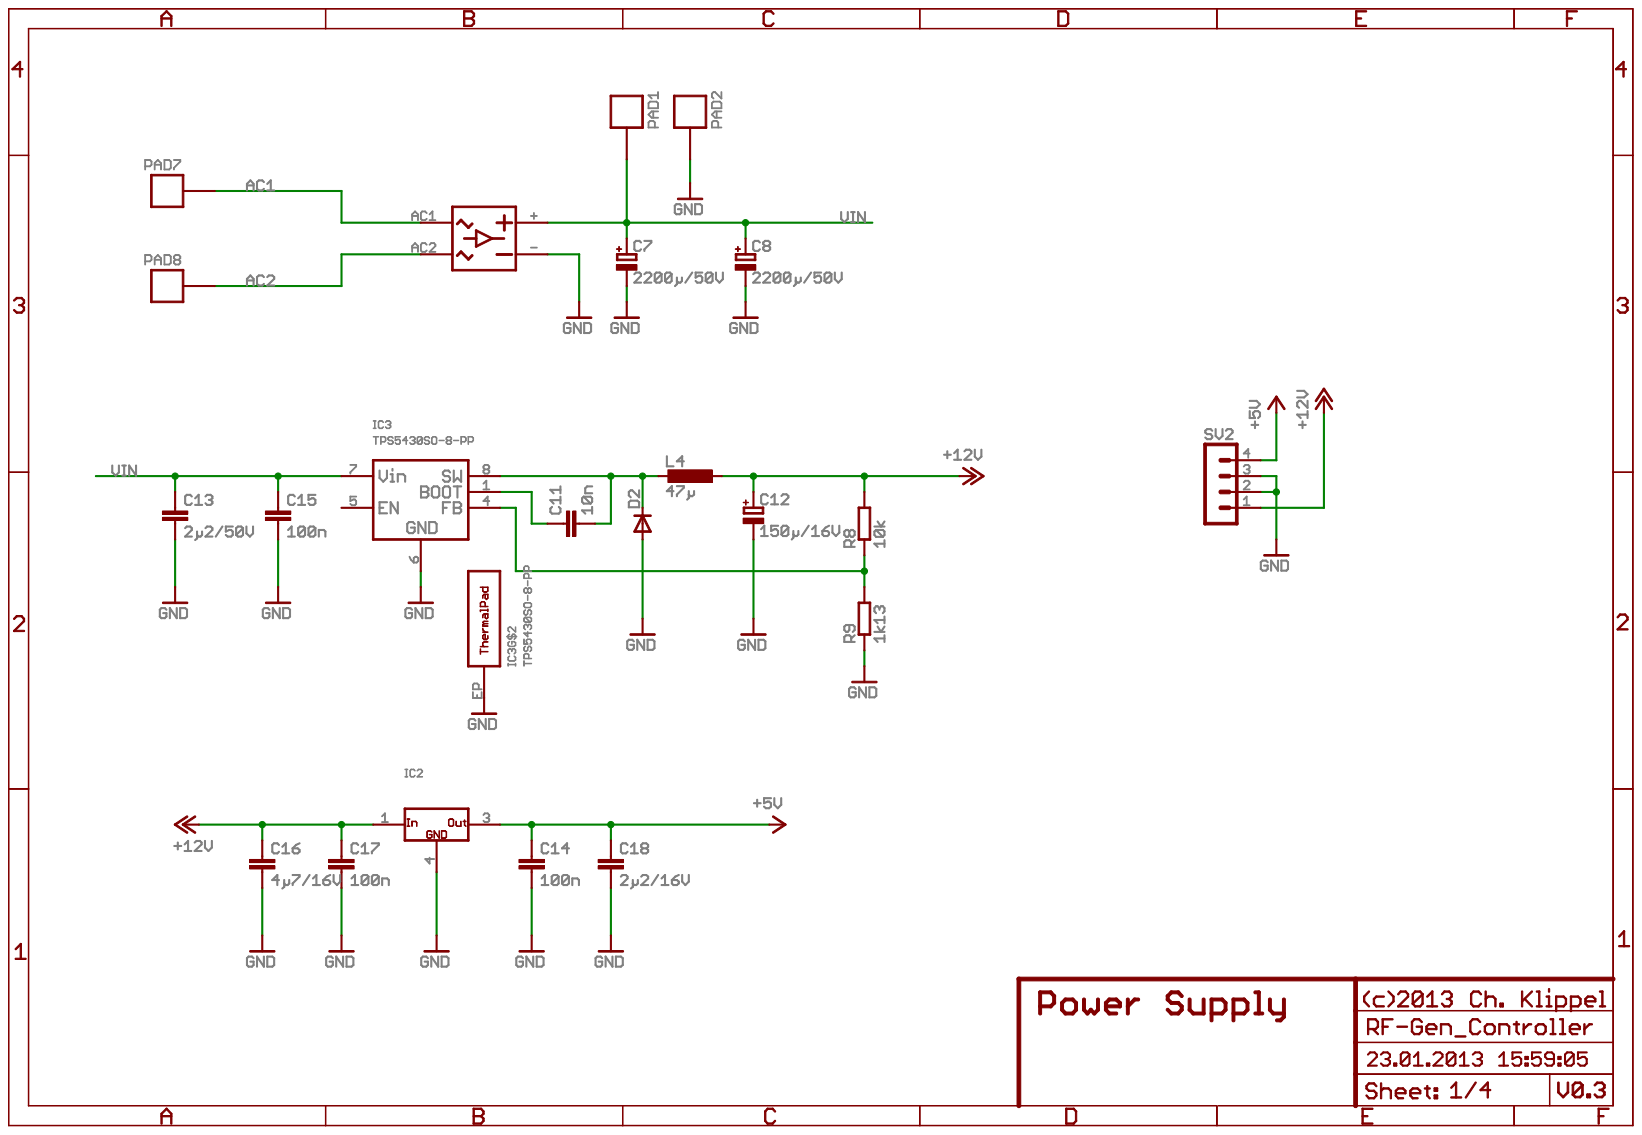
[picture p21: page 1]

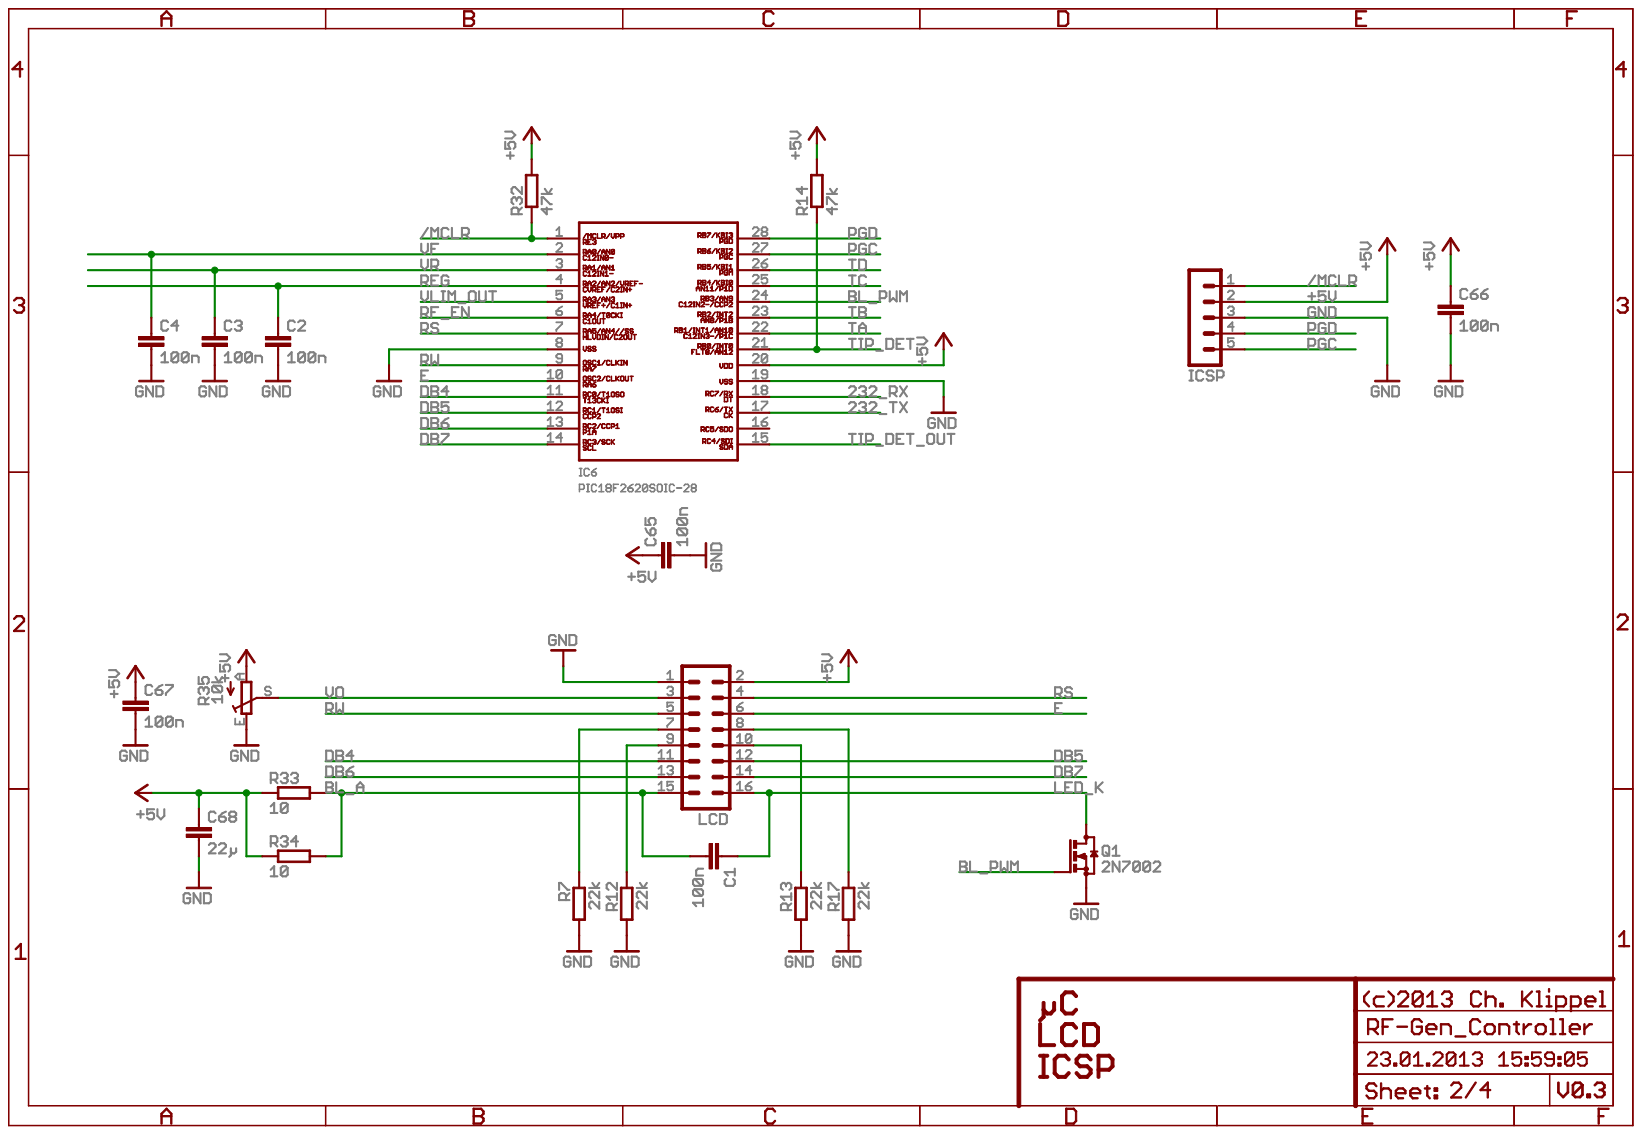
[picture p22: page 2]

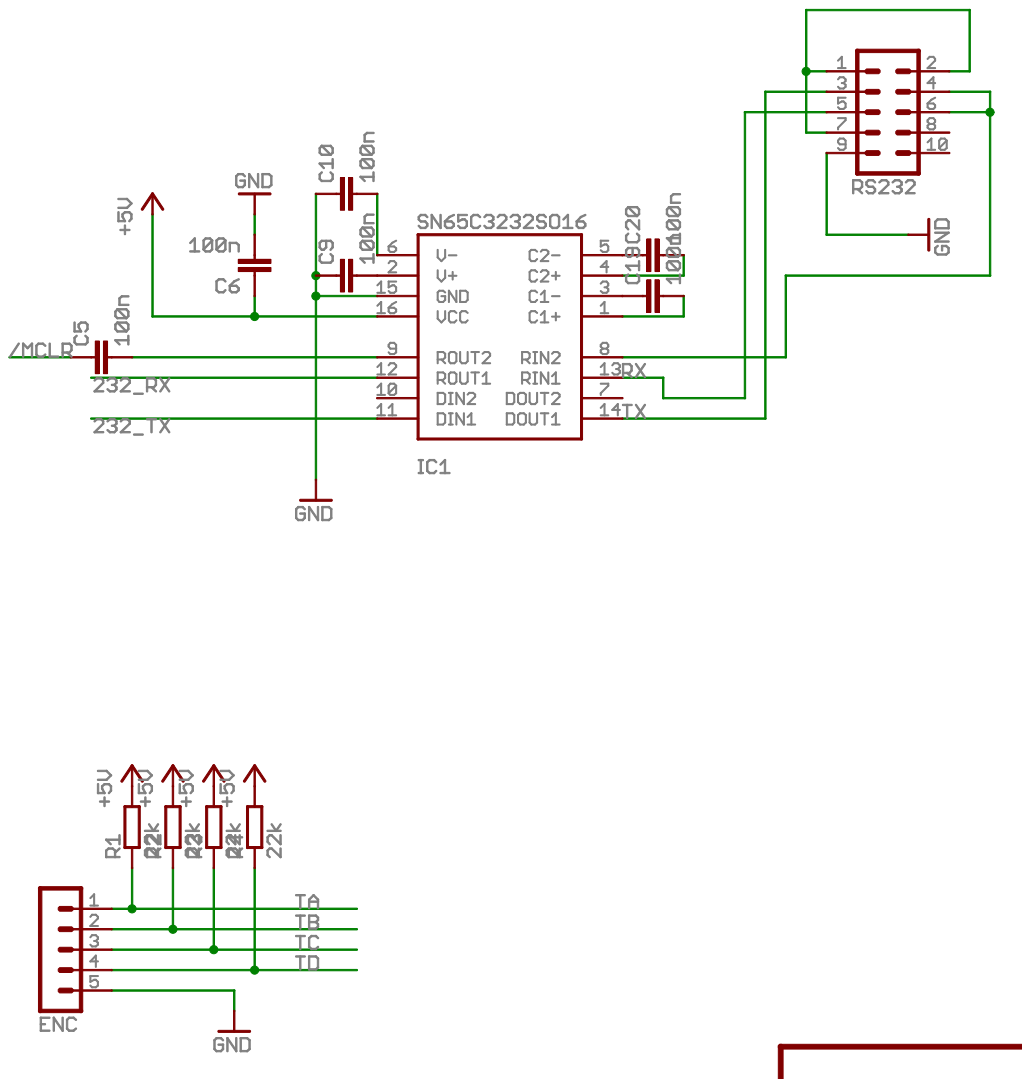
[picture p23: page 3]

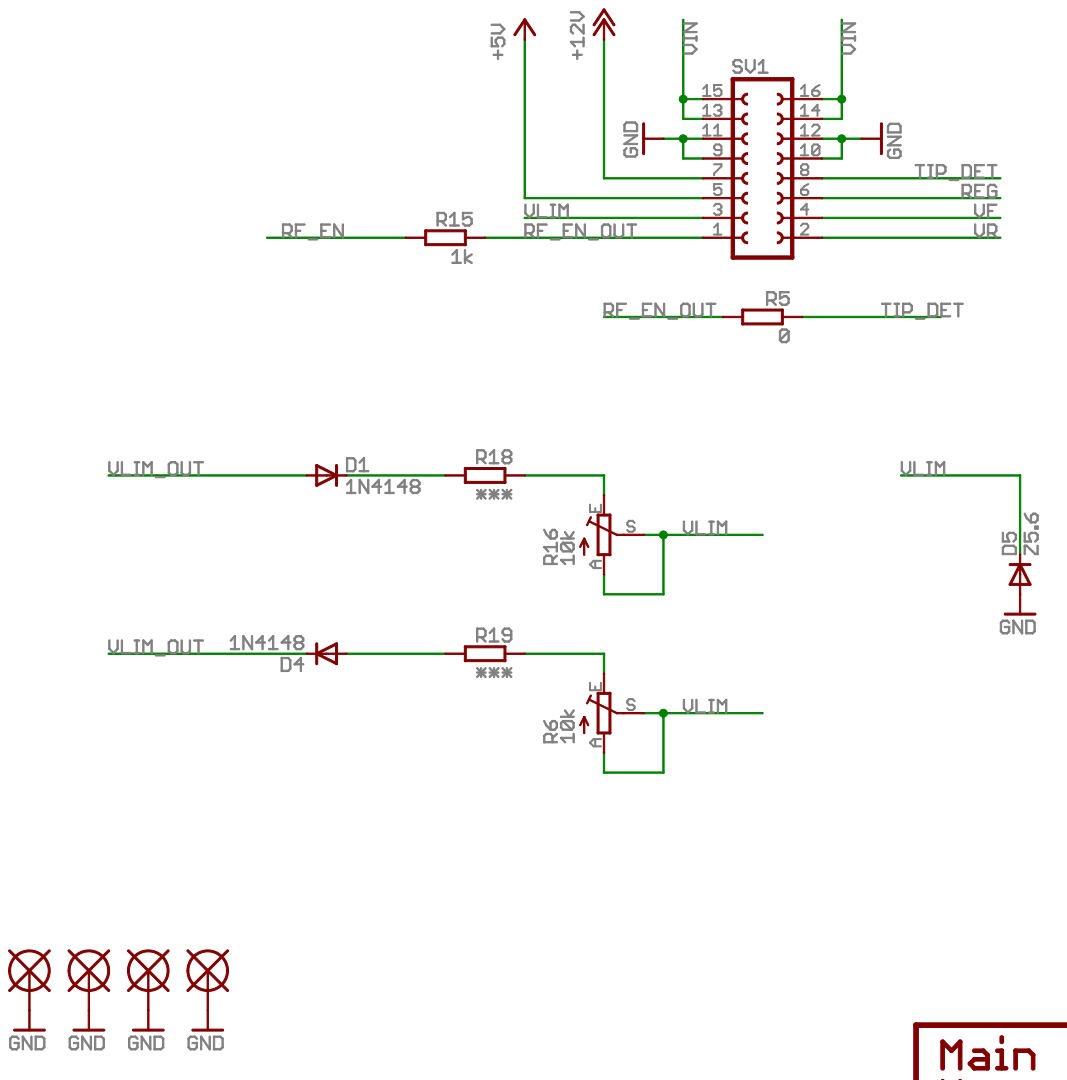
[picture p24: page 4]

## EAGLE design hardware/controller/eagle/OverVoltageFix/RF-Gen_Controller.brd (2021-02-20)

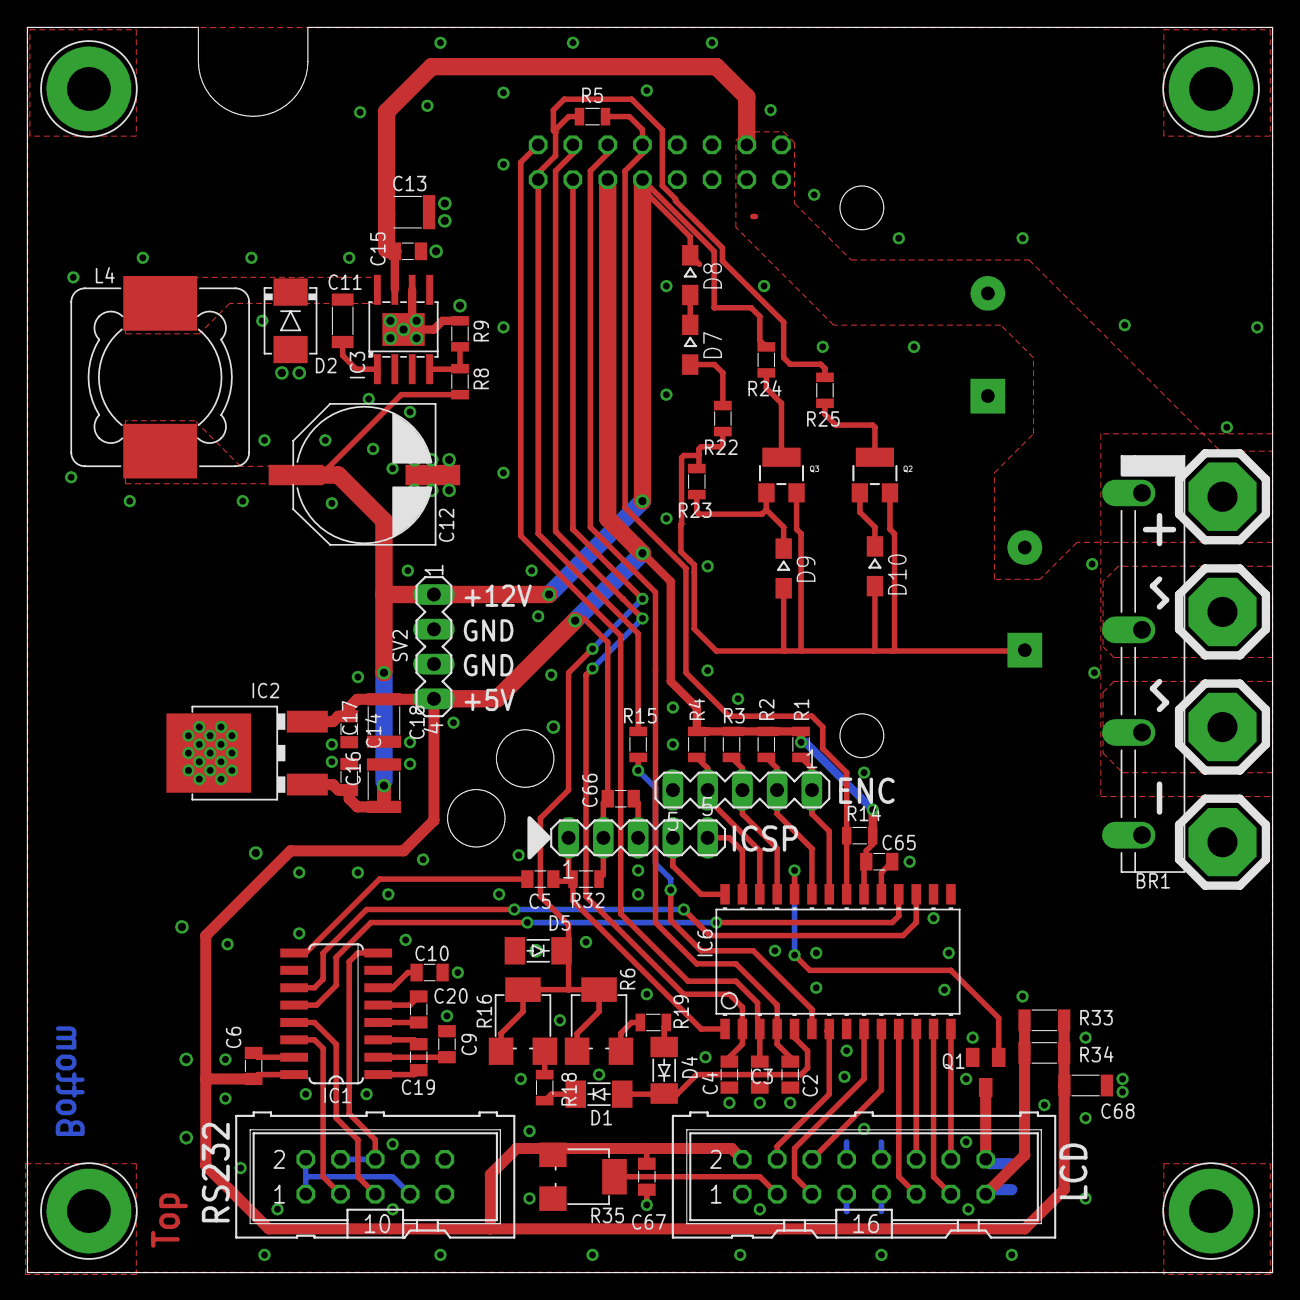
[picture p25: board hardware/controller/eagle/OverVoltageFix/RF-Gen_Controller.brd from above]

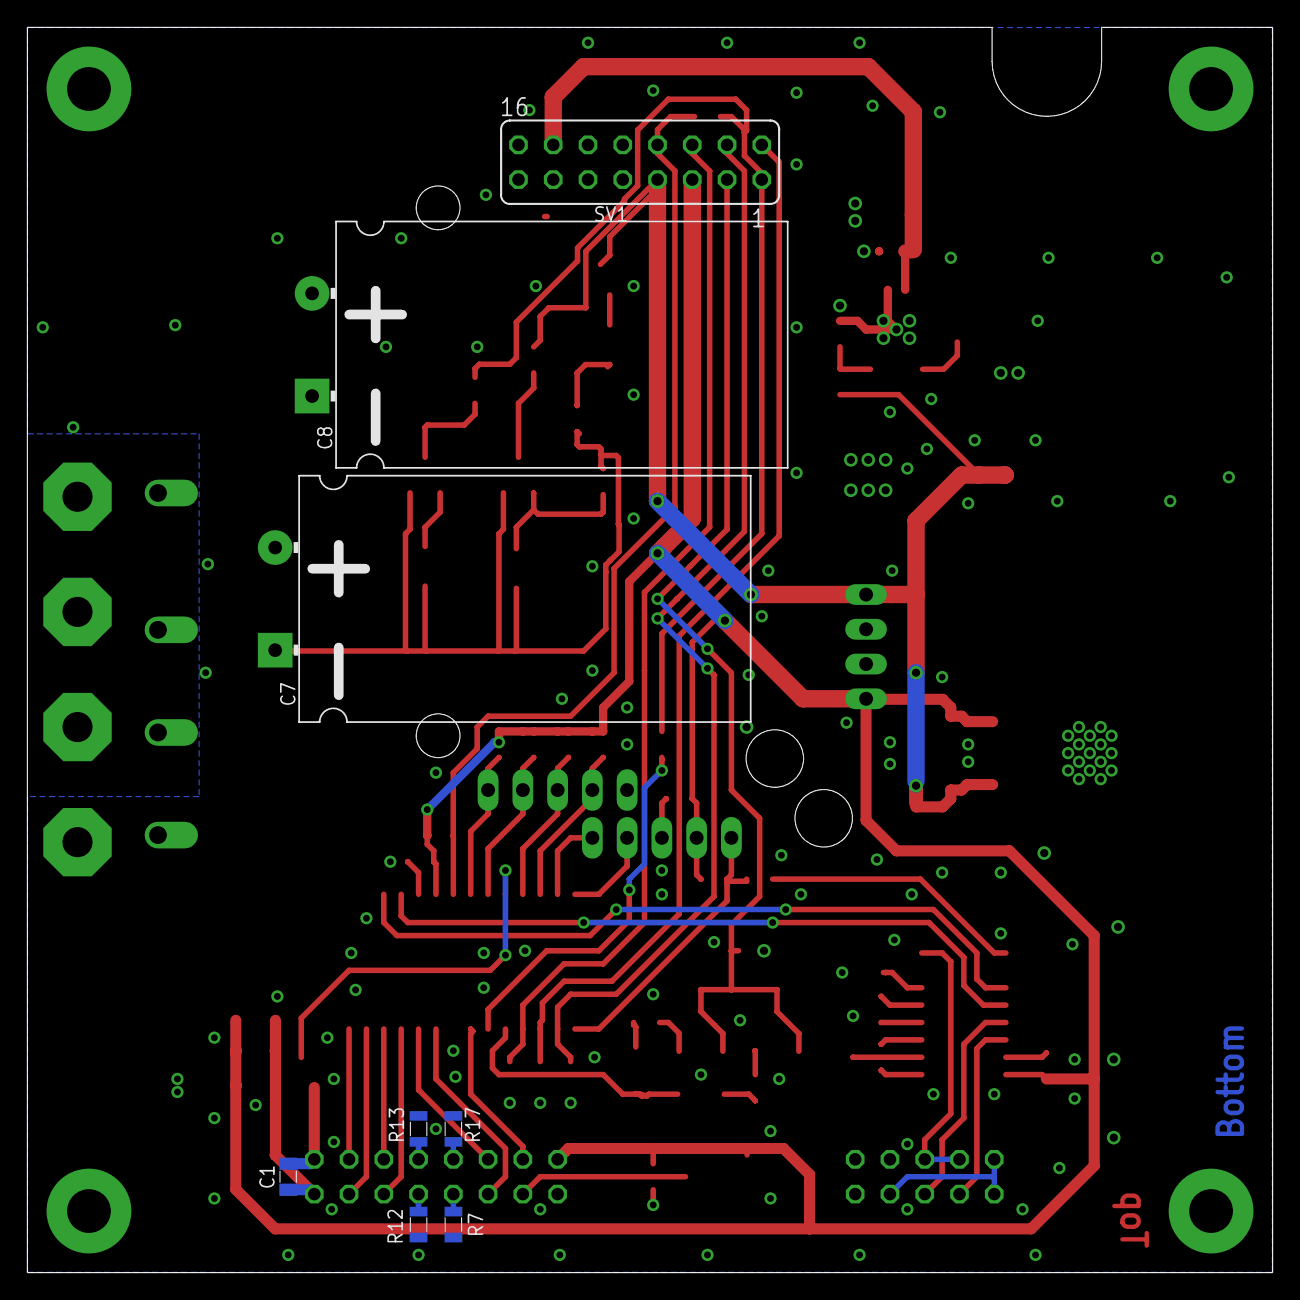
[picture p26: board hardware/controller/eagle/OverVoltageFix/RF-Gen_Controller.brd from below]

Board: 2 copper layers, 91.0 x 91.0 mm, 80 parts (8 on the bottom side), 60 nets.

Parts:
BR1: RECTIFIERGBJ_THT; GBJ_THT
C1, C2, C3, C4, C5, C6, C9, C10, C14, C15, C17, C19, C20, C65, C66, C67: 100n; C_0805_REFLOW
C7, C8: 2200µ/50V; CAP_EEUHD1H_VERT2
C11: 10n; C_1206_REFLOW
C12: 150µ/16V; CAP_AL_100_108
C13: 2µ2/50V; C_1210_REFLOW
C16: 4µ7/16V; C_1210_REFLOW
C18: 2µ2/16V; C_1210_REFLOW
C68: 22µ; C_1206_REFLOW
D1, D4: 1N4148; LL-34
D2: SMB
D5: Z5.6; LL-34
D7: 10V; SOD323-W
D8: 12V; SOD323-W
D9, D10: 5V6; SOD323-W
ENC: MA05-1
IC1: SN65C3232SO16; SO16
IC2: DPAK-3
IC3: TPS5430SO-8-PP; SO-8-PP
IC6: PIC18F2620SOIC-28; SOIC-28
ICSP: MA05-1
L4: 47µ; SSR1260
LCD: ML16
PAD1, PAD2, PAD7, PAD8: SOLPAD_5
Q1: 2N7002; SOT23
Q2, Q3: 2N7000; SOT23-W
R1, R2, R3, R4, R7, R12, R13, R17, R24: 22k; R_0805_REFLOW
R5: 0; R_0805_REFLOW
R6, R16, R35: 10k; 3364W
R8: 10k; R_0805_REFLOW
R9: 1k13; R_0805_REFLOW
R14, R32: 47k; R_0805_REFLOW
R15, R23, R25: 1k; R_0805_REFLOW
R18, R19: ***; R_0805_REFLOW
R22: 2k2; R_0805_REFLOW
R33, R34: 10; R_1206_REFLOW
RS232: ML10
SV1: FE08-2
SV2: MA04-1
U$6, U$7, U$8, U$9: MOUNTPADM3_WASHER; PAD_M3_WASHER

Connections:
232_RX: IC1.12, IC6.18
232_TX: IC1.11, IC6.17
+12V: C12.+, C16.P$1, C17.P$1, D8.C, IC2.1, L4.1, R8.P$2, R24.P$2, SV1.7, SV2.1
/MCLR: C5.P$1, IC6.1, ICSP.1, R32.P$1
AC1: BR1.AC1, PAD7.P$1
AC2: BR1.AC2, PAD8.P$1
BL_A: C1.P$2, LCD.15, R33.P$2, R34.P$2
BL_PWM: IC6.24, Q1.1
DB4: IC6.11, LCD.11
DB5: IC6.12, LCD.12
DB6: IC6.13, LCD.13
DB7: IC6.14, LCD.14
DETECT: RS232.1, RS232.2, RS232.7
E: IC6.10, LCD.6
GND: BR1.-, C2.P$2, C3.P$2, C4.P$2, C6.P$2, C7.-, C8.-, C9.P$1, C10.P$1, C12.-, C13.P$2, C14.P$2, C15.P$2, C16.P$2, C17.P$2, C18.P$2, C65.P$2, C66.P$2, C67.P$2, C68.P$2, D2.A, D5.A, D9.A, D9.C, D10.A, ENC.5, IC1.15, IC2.4, IC3.6, IC3.EP, IC6.8, IC6.19, ICSP.3, LCD.1, PAD2.P$1, Q1.2, Q2.2, Q3.1, Q3.2, R7.P$2, R9.P$1, R12.P$2, R13.P$2, R17.P$2, R22.P$1, R23.P$1, R23.P$2, R35.E, RS232.9, SV1.9, SV1.10, SV1.11, SV1.12, SV2.2, SV2.3, U$6.P$1, U$7.P$1, U$8.P$1, U$9.P$1
LED_K: C1.P$1, LCD.16, Q1.3
unnamed: R6.E, R19.P$1
unnamed: R16.E, R18.P$1
unnamed: LCD.9, R12.P$1
unnamed: LCD.7, R7.P$1
unnamed: LCD.10, R13.P$1
unnamed: C9.P$2, IC1.2
unnamed: C5.P$2, IC1.9
unnamed: C10.P$2, IC1.6
unnamed: C11.P$1, IC3.1
unnamed: IC3.4, R8.P$1, R9.P$2
unnamed: C19.P$1, IC1.3
unnamed: C20.P$1, IC1.5
unnamed: LCD.8, R17.P$1
unnamed: D1.C, R18.P$2
unnamed: D4.A, R19.P$2
unnamed: C20.P$2, IC1.4
unnamed: C19.P$2, IC1.1
PGC: IC6.27, ICSP.5
PGD: IC6.28, ICSP.4
REG: C2.P$1, IC6.4, SV1.6
RF_EN: IC6.6, R15.P$2
RF_EN_OUT: C6.P$1, C14.P$1, C18.P$1, C65.P$1, C66.P$1, C67.P$1, C68.P$1, IC1.16, IC2.3, IC6.20, ICSP.2, LCD.2, R1.P$2, R2.P$2, R3.P$2, R4.P$2, R5.P$2, R14.P$2, R15.P$1, R25.P$2, R32.P$2, R33.P$1, R34.P$1, R35.A, SV1.1, SV1.5, SV2.4
RS: IC6.7, LCD.4
RW: IC6.9, LCD.5
RX: IC1.13, RS232.5
S$2: D7.A, R22.P$2
S$3: D7.C, D8.A
S$7: D10.C, Q2.1
S$8: Q3.3, R24.P$1
S$9: Q2.3, R25.P$1
SRESET: IC1.8, RS232.4, RS232.6
SW12: C11.P$2, D2.C, IC3.8, L4.2
TA: ENC.1, IC6.22, R1.P$1
TB: ENC.2, IC6.23, R2.P$1
TC: ENC.3, IC6.25, R3.P$1
TD: ENC.4, IC6.26, R4.P$1
TIP_DET: IC6.21, R5.P$1, R14.P$1, SV1.8
TX: IC1.14, RS232.3
VF: C4.P$1, IC6.2, SV1.4
VIN: BR1.+, C7.+, C8.+, C13.P$1, C15.P$1, IC3.7, PAD1.P$1, SV1.13, SV1.14, SV1.15, SV1.16
VLIM: D5.C, R6.A, R6.S, R16.A, R16.S, SV1.3
VLIM_OUT: D1.A, D4.C, IC6.5
VO: LCD.3, R35.S
VR: C3.P$1, IC6.3, SV1.2

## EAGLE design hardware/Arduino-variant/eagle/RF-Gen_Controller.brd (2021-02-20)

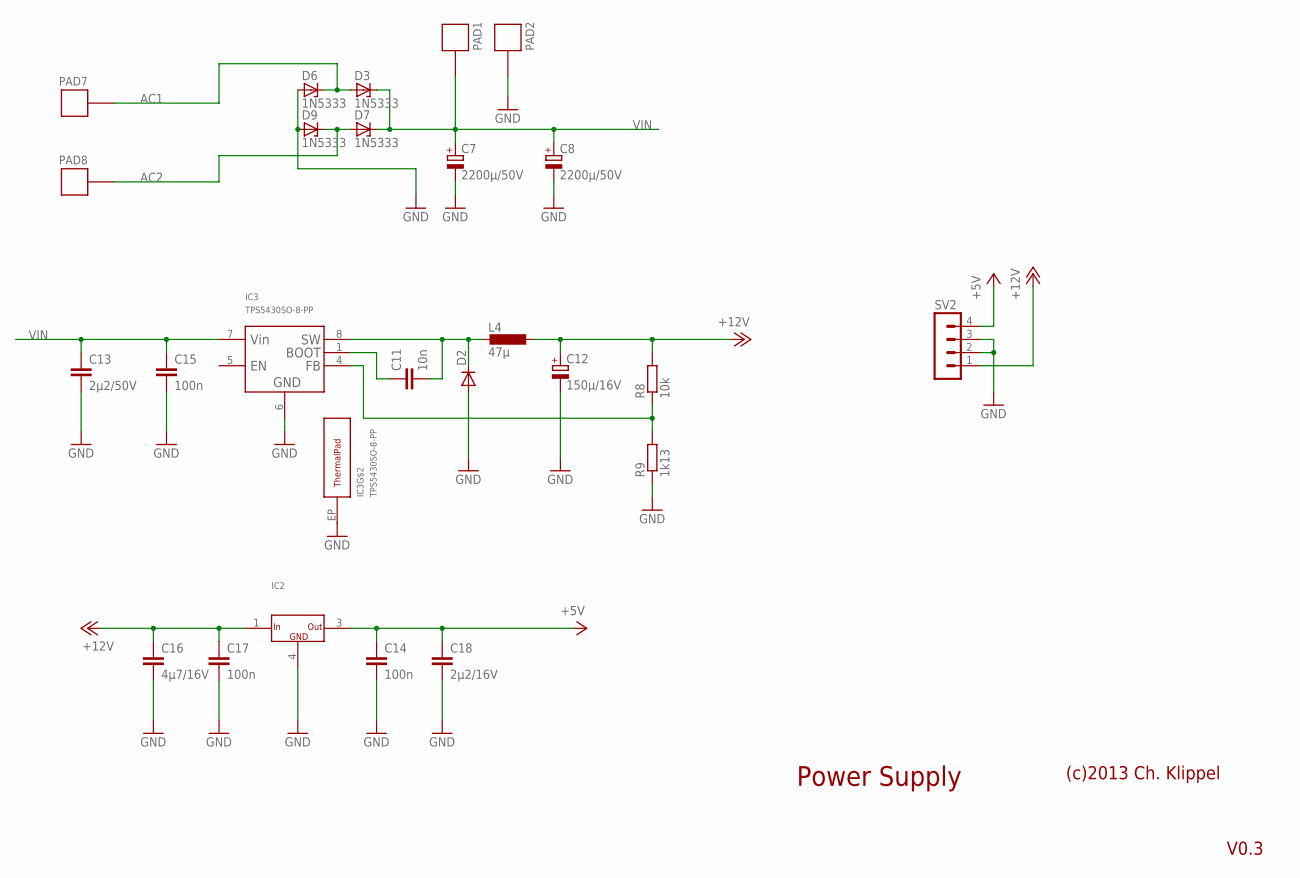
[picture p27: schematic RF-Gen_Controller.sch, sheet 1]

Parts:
C7, C8: 2200µ/50V; CAP_EEUHD1H_VERT2
C11: 10n; C_1206_REFLOW
C12: 150µ/16V; CAP_AL_100_108
C13: 2µ2/50V; C_1210_REFLOW
C14, C15, C17: 100n; C_0805_REFLOW
C16: 4µ7/16V; C_1210_REFLOW
C18: 2µ2/16V; C_1210_REFLOW
D2: DIODE-SMB; SMB
D3, D6, D7, D9: 1N5333; C1702-15
IC2: VREG_3DPAK-3; DPAK-3
IC3: TPS5430SO-8-PP; SO-8-PP
L4: 47µ; SSR1260
PAD1, PAD2, PAD7, PAD8: SOLPAD5MM; SOLPAD_5
R8: 10k; R_0805_REFLOW
R9: 1k13; R_0805_REFLOW
SV2: MA04-1

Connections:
+5V: C14.P$1 (1), C18.P$1 (1), IC2.3 (OUT), SV2.4; also elsewhere on the board
+12V: C12.+, C16.P$1 (1), C17.P$1 (1), IC2.1 (IN), L4.1, R8.P$2 (2), SV2.1; also elsewhere on the board
AC1: D3.A, D6.C, PAD7.P$1
AC2: D7.A, D9.C, PAD8.P$1
GND: C7.-, C8.-, C12.-, C13.P$2 (2), C14.P$2 (2), C15.P$2 (2), C16.P$2 (2), C17.P$2 (2), C18.P$2 (2), D2.A, D6.A, D9.A, IC2.4 (GND), IC3.6 (GND), IC3.EP (THERMALPAD), PAD2.P$1, R9.P$1 (1), SV2.2, SV2.3; also elsewhere on the board
unnamed: C11.P$1 (1), IC3.1 (BOOT)
unnamed: IC3.4 (FB), R8.P$1 (1), R9.P$2 (2)
SW12: C11.P$2 (2), D2.C, IC3.8 (SW), L4.2
VIN: C7.+, C8.+, C13.P$1 (1), C15.P$1 (1), D3.C, D7.C, IC3.7 (VIN), PAD1.P$1; also elsewhere on the board

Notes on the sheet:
Power Supply
(c)2013 Ch. Klippel
V0.3

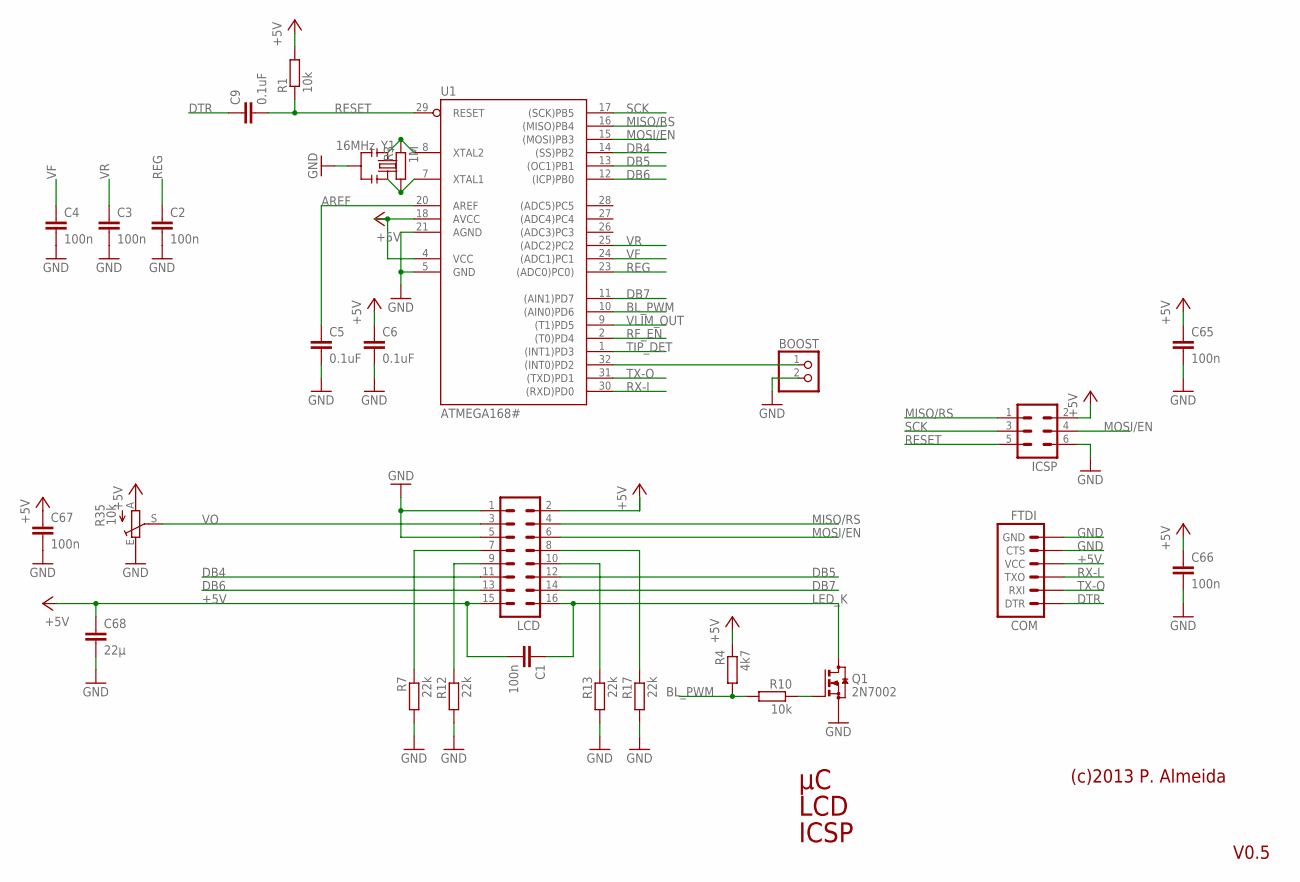
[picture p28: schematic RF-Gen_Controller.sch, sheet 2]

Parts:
BOOST: PINHD-1X2/90; 1X02/90
C1, C2, C3, C4, C65, C66, C67: 100n; C_0805_REFLOW
C5, C6, C9: 0.1uF; C_0805_REFLOW
C68: 22µ; C_1206_REFLOW
FTDI: COM; 1X06
ICSP: ML6
LCD: ML16
Q1: 2N7002; SOT23
R1, R10: 10k; R_0805_REFLOW
R3: 1M; R_0805_REFLOW
R4: 4k7; R_0805_REFLOW
R7, R12, R13, R17: 22k; R_0805_REFLOW
R35: 10k; 3364W
U1: ATMEGA168#; TQFP32-08
Y1: 16MHz; RESONATOR-SMD

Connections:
+5V: C1.P$2 (2), C6.P$1 (1), C65.P$1 (1), C66.P$1 (1), C67.P$1 (1), C68.P$1 (1), FTDI.4 (VCC), ICSP.2, LCD.2, LCD.15, R1.P$2 (2), R4.P$1 (1), R35.A, U1.4 (VCC), U1.18 (AVCC); also elsewhere on the board
AREF: C5.P$1 (1), U1.20 (AREF)
BL_PWM: R4.P$2 (2), R10.P$2 (2), U1.10 ((AIN0)PD6)
DB4: LCD.11, U1.14 ((SS)PB2)
DB5: LCD.12, U1.13 ((OC1)PB1)
DB6: LCD.13, U1.12 ((ICP)PB0)
DB7: LCD.14, U1.11 ((AIN1)PD7)
DTR: C9.P$1 (1), FTDI.1 (DTR)
GND: BOOST.2, C2.P$2 (2), C3.P$2 (2), C4.P$2 (2), C5.P$2 (2), C6.P$2 (2), C65.P$2 (2), C66.P$2 (2), C67.P$2 (2), C68.P$2 (2), FTDI.5 (CTS), FTDI.6 (GND), ICSP.6, LCD.1, LCD.5, Q1.2 (S), R7.P$2 (2), R12.P$2 (2), R13.P$2 (2), R17.P$2 (2), R35.E, U1.5 (GND), U1.21 (AGND), Y1.2; also elsewhere on the board
LED_K: C1.P$1 (1), LCD.16, Q1.3 (D)
MISO/RS: ICSP.1, LCD.4, U1.16 ((MISO)PB4)
MOSI/EN: ICSP.4, LCD.6, U1.15 ((MOSI)PB3)
unnamed: LCD.9, R12.P$1 (1)
unnamed: LCD.7, R7.P$1 (1)
unnamed: LCD.10, R13.P$1 (1)
unnamed: Q1.1 (G), R10.P$1 (1)
unnamed: BOOST.1, U1.32 ((INT0)PD2)
unnamed: R3.P$1 (1), U1.8 (XTAL2), Y1.1
unnamed: R3.P$2 (2), U1.7 (XTAL1), Y1.3
unnamed: LCD.8, R17.P$1 (1)
REG: C2.P$1 (1), U1.23 ((ADC0)PC0)); also elsewhere on the board
RESET: C9.P$2 (2), ICSP.5, R1.P$1 (1), U1.29 (RESET)
RF_EN: U1.2 ((T0)PD4); also elsewhere on the board
RX-I: FTDI.3 (TXO), U1.30 ((RXD)PD0)
SCK: ICSP.3, U1.17 ((SCK)PB5)
TIP_DET: U1.1 ((INT1)PD3); also elsewhere on the board
TX-O: FTDI.2 (RXI), U1.31 ((TXD)PD1)
VF: C4.P$1 (1), U1.24 ((ADC1)PC1); also elsewhere on the board
VLIM_OUT: U1.9 ((T1)PD5); also elsewhere on the board
VO: LCD.3, R35.S
VR: C3.P$1 (1), U1.25 ((ADC2)PC2); also elsewhere on the board

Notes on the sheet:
LCD
ICSP
(c)2013 P. Almeida
V0.5

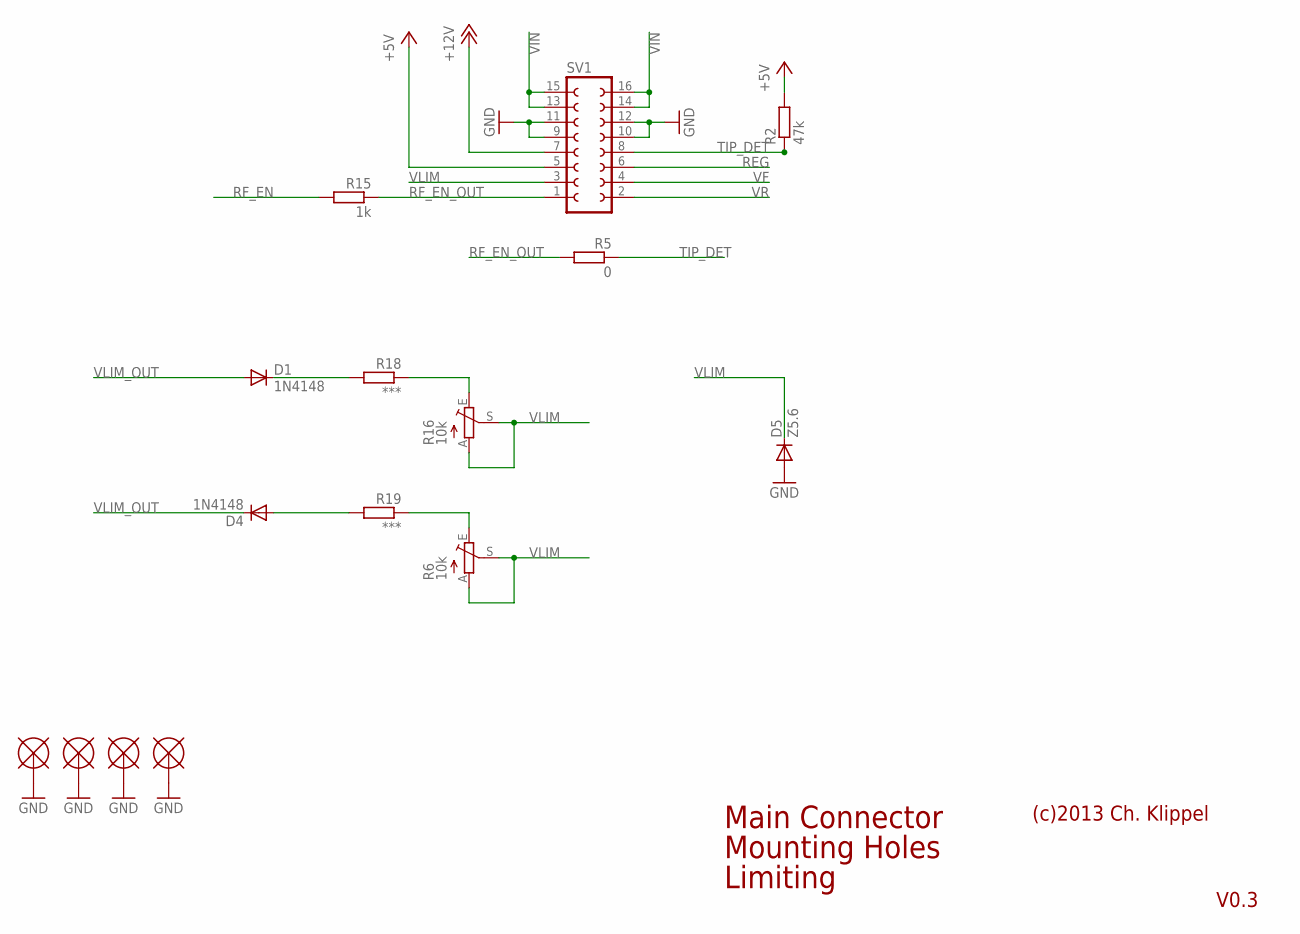
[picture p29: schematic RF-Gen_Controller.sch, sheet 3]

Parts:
D1, D4: 1N4148; LL-34
D5: Z5.6; LL-34
R2: 47k; R_0805_REFLOW
R5: 0; R_0805_REFLOW
R6, R16: 10k; 3364W
R15: 1k; R_0805_REFLOW
R18, R19: ***; R_0805_REFLOW
SV1: FE08-2
U$6, U$7, U$8, U$9: MOUNTPADM3_WASHER; PAD_M3_WASHER

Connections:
+5V: R2.P$2 (2), SV1.5; also elsewhere on the board
+12V: SV1.7; also elsewhere on the board
GND: D5.A, SV1.9, SV1.10, SV1.11, SV1.12, U$6.P$1, U$7.P$1, U$8.P$1, U$9.P$1; also elsewhere on the board
unnamed: R6.E, R19.P$1 (1)
unnamed: R16.E, R18.P$1 (1)
unnamed: D1.C, R18.P$2 (2)
unnamed: D4.A, R19.P$2 (2)
REG: SV1.6; also elsewhere on the board
RF_EN: R15.P$2 (2); also elsewhere on the board
RF_EN_OUT: R5.P$2 (2), R15.P$1 (1), SV1.1
TIP_DET: R2.P$1 (1), R5.P$1 (1), SV1.8; also elsewhere on the board
VF: SV1.4; also elsewhere on the board
VIN: SV1.13, SV1.14, SV1.15, SV1.16; also elsewhere on the board
VLIM: D5.C, R6.A, R6.S, R16.A, R16.S, SV1.3
VLIM_OUT: D1.A, D4.C; also elsewhere on the board
VR: SV1.2; also elsewhere on the board

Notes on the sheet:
Main Connector
Mounting Holes
Limiting
(c)2013 Ch. Klippel
V0.3

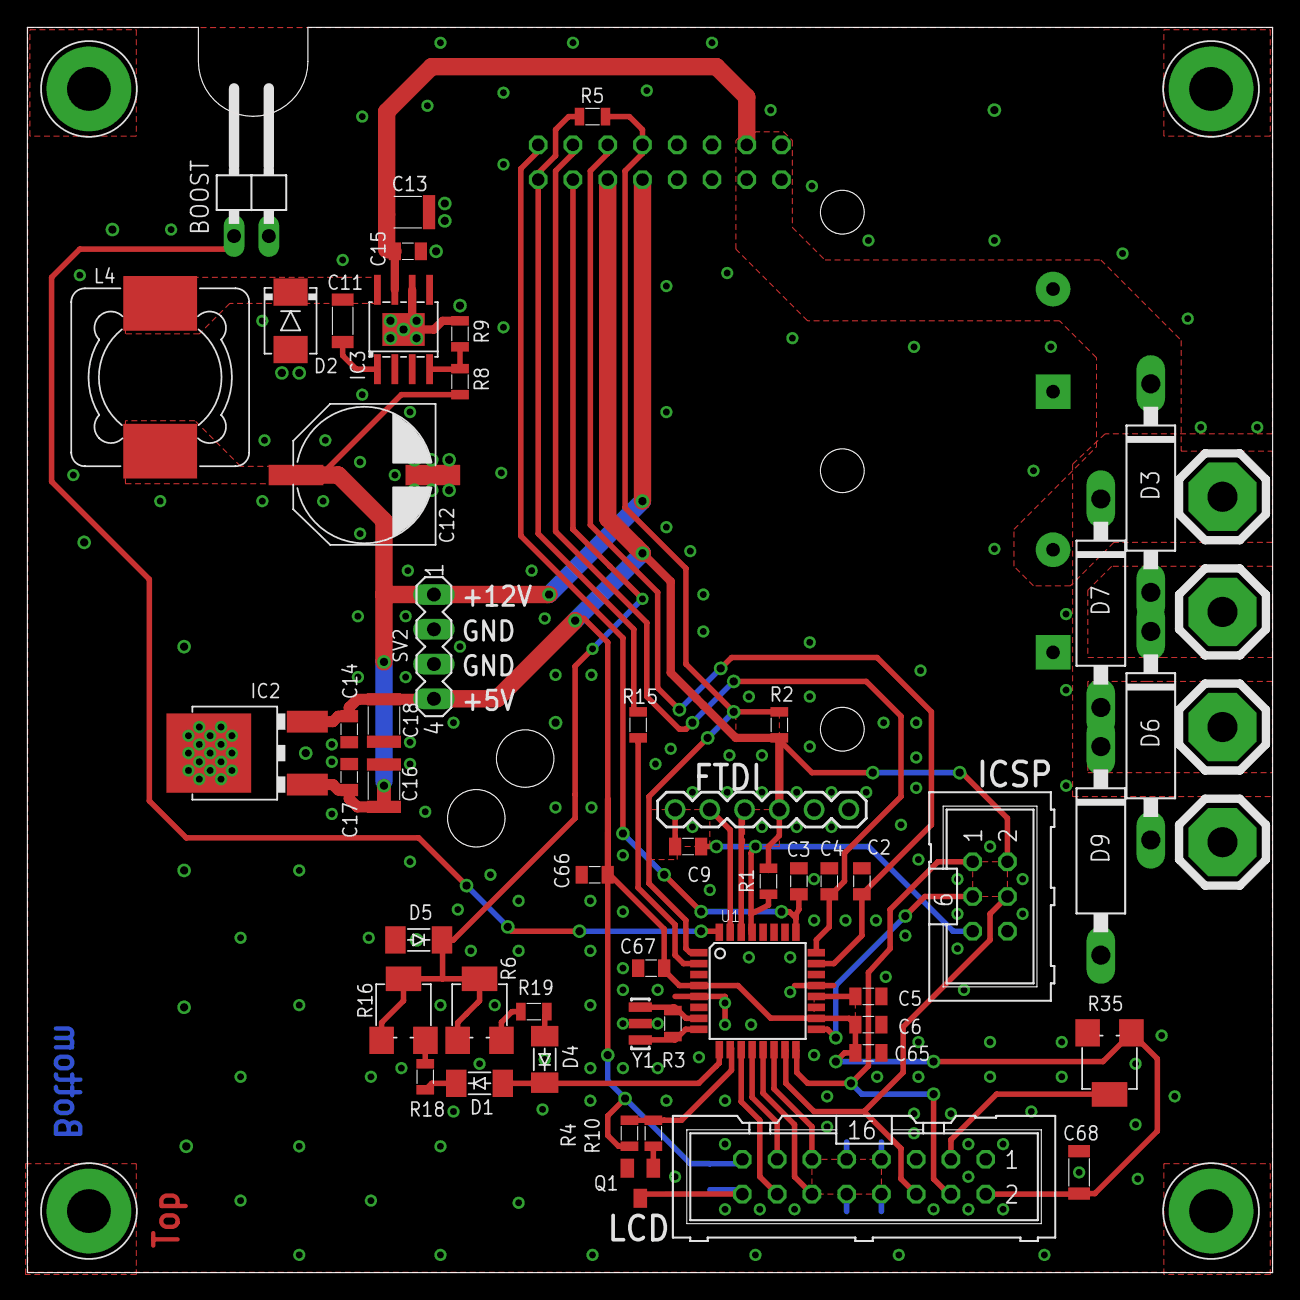
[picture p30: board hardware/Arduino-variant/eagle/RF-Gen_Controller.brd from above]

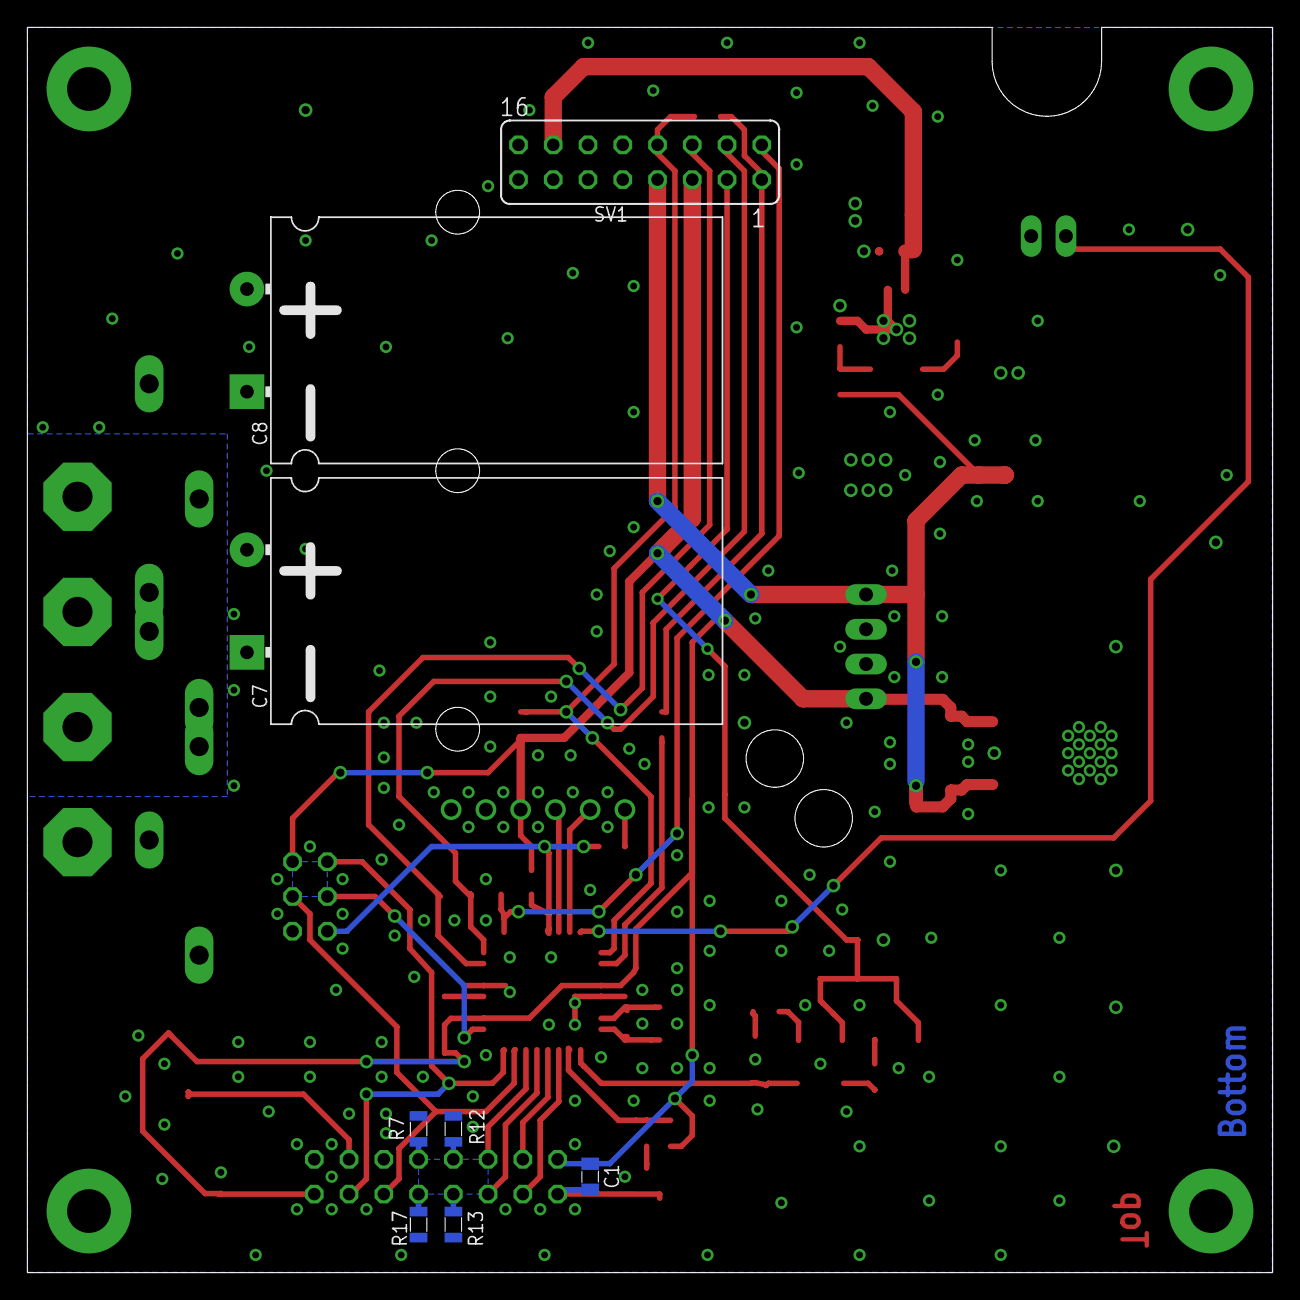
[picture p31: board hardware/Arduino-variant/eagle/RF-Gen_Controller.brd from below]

Board: 2 copper layers, 91.0 x 91.0 mm, 67 parts (8 on the bottom side), 44 nets.

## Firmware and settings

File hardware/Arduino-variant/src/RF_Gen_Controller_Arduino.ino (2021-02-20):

#include <LiquidCrystal.h>

LiquidCrystal lcd(12, 11, 10, 9, 8, 7); // LiquidCrystal(rs, enable, d4, d5, d6, d7)

int TIP_DET_PIN           = 3;          // Digital PIN 0-13
int RF_EN_PIN             = 4;          // Digital PIN 0-13
int VLIM_PIN              = 5;          // Digital PIN 0-13
int BOOST_PIN             = 2;          // Digital PIN 0-13
int REG_PIN               = A0;         // Analog PIN A0-A5
int VF_PIN                = A1;         // Analog PIN A0-A5
int VR_PIN                = A2;         // Analog PIN A0-A5
int BACKLIGHT_PIN         = 6;          // PWM PIN 3, 5, 6, 9, 10, or 11

float VF, VR, REG, VSWR;

int SAMPLES               = 16;
int NO_TIP_BACKLIGHT_VAL  = 50;         // 0-255
int POWER_BACKLIGHT_VAL   = 255;        // 0-255
int BOOST_BACKLIGHT_VAL   = 255;        // 0-255
int READY_BACKLIGHT_VAL   = 255;        // 0-255
int ECO_BACKLIGHT_VAL     = 50;         // 0-255
int STANDBY_BACKLIGHT_VAL = 0;          // 0-255

int VSWR_MAX              = 1000;
int READY_VAL             = 10;         // 0-99
    
long ECO_TIME             = 5000;       // ms
long STANDBY_TIME         = 10000;      // ms
  
unsigned long LASTMILLIS;
int PERCENT, LASTPERCENT, STATE, LASTSTATE;

byte r0[8] = {
  B00000, 
  B00000,
  B00000,
  B00000,
  B00000,
  B00000,
  B00000,
  B00000
}; // 0 / 5
byte r1[8] = {
  B10000, 
  B10000,
  B10000,
  B10000,
  B10000,
  B10000,
  B10000,
  B10000
}; // 1 / 5
byte r2[8] = {
  B11000, 
  B11000,
  B11000,
  B11000,
  B11000,
  B11000,
  B11000,
  B11000
}; // 2 / 5 
byte r3[8] = {
  B11100, 
  B11100,
  B11100,
  B11100,
  B11100,
  B11100,
  B11100,
  B11100
}; // 3 / 5
byte r4[8] = {
  B11110, 
  B11110,
  B11110,
  B11110,
  B11110,
  B11110,
  B11110,
  B11110
}; // 4 / 5
byte r5[8] = {
  B11111, 
  B11111,
  B11111,
  B11111,
  B11111,
  B11111,
  B11111,
  B11111
}; // 5 / 5

void draw_state(int State) {
  
  if (State == 0){
      lcd.setCursor(4, 0);
      lcd.print("STANDBY");
      digitalWrite(RF_EN_PIN, LOW);
      analogWrite(BACKLIGHT_PIN, STANDBY_BACKLIGHT_VAL);}
      
  if (State == 1){
      lcd.setCursor(4, 0);
      lcd.print("  ECO  ");
      pinMode(VLIM_PIN, OUTPUT);
      digitalWrite(VLIM_PIN, HIGH);
      analogWrite(BACKLIGHT_PIN, ECO_BACKLIGHT_VAL);}
      
  if (State == 2){
      lcd.setCursor(4, 0);
      lcd.print(" READY ");
      pinMode(VLIM_PIN, INPUT);
      analogWrite(BACKLIGHT_PIN, READY_BACKLIGHT_VAL);}
      
  if (State == 3){
      lcd.setCursor(4, 0);
      lcd.print(" POWER ");
      pinMode(VLIM_PIN, INPUT);
      analogWrite(BACKLIGHT_PIN, POWER_BACKLIGHT_VAL);}
      
  if (State == 4){
      lcd.setCursor(4, 0);
      lcd.print(" BOOST ");
      digitalWrite(RF_EN_PIN, HIGH);
      pinMode(VLIM_PIN, OUTPUT);
      digitalWrite(VLIM_PIN, LOW);
      analogWrite(BACKLIGHT_PIN, BOOST_BACKLIGHT_VAL);}
      
  if (State == 5){
      lcd.setCursor(4, 0);
      lcd.print("NO  TIP");
      digitalWrite(RF_EN_PIN, LOW);
      analogWrite(BACKLIGHT_PIN, NO_TIP_BACKLIGHT_VAL);}
  
}

void draw_bargraph(int percent) {
  int i, cp, cl;

  if (percent < READY_VAL){
      lcd.setCursor(14, 1);
      lcd.print("0");
      lcd.print(percent);}
  else { 
      lcd.setCursor(14, 1);
      lcd.print(percent);}

  lcd.setCursor(0, 1);
  
  percent = map(percent, 0, 99, 0, 70);
  cp = percent / 5;
  cl = percent % 5;
  
  for(i = 0; i < cp; ++i)
    lcd.write(5);
  if(cl != 0)
    lcd.write(cl);

  for(i = 0; i < 14 - (cp + (cl ? 1 : 0)); ++i)
    lcd.write((uint8_t)0);
}

void setup(){
  
  Serial.begin(9600);
  pinMode(TIP_DET_PIN, INPUT);
  digitalWrite(TIP_DET_PIN, HIGH);
  pinMode(BOOST_PIN, INPUT);
  digitalWrite(BOOST_PIN, HIGH);
  pinMode(RF_EN_PIN, OUTPUT);
  pinMode(BACKLIGHT_PIN, OUTPUT);
  analogWrite(BACKLIGHT_PIN, BOOST_BACKLIGHT_VAL);
   
  lcd.createChar(0, r0);
  lcd.createChar(1, r1);
  lcd.createChar(2, r2);
  lcd.createChar(3, r3);
  lcd.createChar(4, r4);
  lcd.createChar(5, r5);

  lcd.begin(16, 2); 
  lcd.clear();
  lcd.setCursor(0, 0);
  lcd.print(" RF-GEN MX-5000 ");
  lcd.setCursor(0, 1);
  lcd.print("   Ver:  2.01   ");
  delay(3000);
  lcd.clear();
  
  PERCENT = 0;
  STATE = 4;
  draw_state(STATE);
  LASTSTATE = STATE;
  draw_bargraph(PERCENT);
  LASTPERCENT = PERCENT;
}

void loop(){
  
REG = 0;
VF  = 0;
VR  = 0;

for (int i = 0; i < SAMPLES; i++){
     REG = REG + analogRead(REG_PIN);
     VF  = VF + analogRead(VF_PIN);
     VR  = VR + analogRead(VR_PIN);
     delay(1);}
     
REG = REG / SAMPLES;
VF  = VF / SAMPLES;
VR  = VR / SAMPLES;

VSWR = (1 + sqrt(VR / VF)) / (1 - sqrt(VR / VF));
PERCENT = map(constrain(VSWR, 0, VSWR_MAX), 0, VSWR_MAX, 99, 0);

Serial.print("REG = ");
Serial.print(REG);
Serial.print("\tVF = ");
Serial.print(VF);
Serial.print("\tVR = ");
Serial.print(VR);
Serial.print("\tVSWR = ");
Serial.print(VSWR);
Serial.print("\tPERCENT = ");
Serial.println(PERCENT);

if (digitalRead(TIP_DET_PIN) == LOW) STATE = 5;                                                     //NO TIP 

else{  
  
if (digitalRead(BOOST_PIN) == LOW) STATE = 4;
  
else {
  
if (LASTPERCENT > PERCENT && LASTSTATE == 4 || PERCENT > READY_VAL && LASTSTATE != 4)  STATE = 3;   //POWER
if (PERCENT > READY_VAL && LASTSTATE == 1 || LASTSTATE == 5)                           STATE = 4;   //BOOST
if (PERCENT < READY_VAL && LASTSTATE != 1 && LASTSTATE != 4 && LASTSTATE != 5)         STATE = 2;   //READY
if (millis() - LASTMILLIS > ECO_TIME)                                                  STATE = 1;   //ECO
if (millis() - LASTMILLIS > STANDBY_TIME)                                              STATE = 0;   //STANDBY
}
}

if (PERCENT > READY_VAL || STATE == 4 || STATE == 5) LASTMILLIS = millis();

if (STATE != LASTSTATE){
    draw_state(STATE);
    LASTSTATE = STATE;}
  
if (PERCENT != LASTPERCENT){
    draw_bargraph(PERCENT);
    LASTPERCENT = PERCENT;}
  
delay(100);
}

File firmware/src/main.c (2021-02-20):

/*
 * (c) 2013 Ch. klippel  -  ck@atelier-klippel.de / c.klippel@gmx.de
 *
 * This code is released under the terms of the GPL, version 2 or newer.
 * See the file COPYING for more information about the license.
 *
 * Changelog:
 *
 * v00.01: - Initial version
 *
 */

#include "rfsupply.h"

voidfunc uifunc;

void default_ui_func(void);

void main_return_func(void)
{
    backlight_leave_temp();
    infodisplay_reset();
    infodisplay_show();
    set_ui_func(default_ui_func);
    encoder_clear_button();
}

void default_ui_func(void)
{
    if(encoder_get_button() == BUTTON_LONGPUSH)
    {
        backlight_enter_temp();
        menu_start((const rom void *) &main_return_func);
        encoder_clear_button();
    }
    else
    {
        infodisplay_show();
    }
}

void modules_init(void)
{
    // the following modules _MUST_ be initialized first in the given order
    config_memory_init();
    uart_init();
    logger_init();
    languages_init();
    config_manager_init();

    // these modules can be initialized in any order
    tip_detect_init();
    time_init();
    lcd_init();
    backlight_init();
    encoder_init();
    adc_init();
    rf_manager_init();
    power_manager_init();

    backlight_mode(active_config.normal_backlight);

    encoder_reset_button();
    encoder_reset();

    infodisplay_init();
}

void main(void)
{
    set_ui_func(default_ui_func);

    hardware_init();
    interrupt_init();
    modules_init();
    
    while(1)
    {
        if(time_get_reset_delta_ticks())
        {
            uifunc();
            power_manager_process();
            
            if(encoder_get_button() != BUTTON_IDLE)
            {
                encoder_reset_all();
            }
            else
            {
                encoder_reset();
            }
        }
    }
}

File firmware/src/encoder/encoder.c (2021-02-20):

/*
 * (c) 2013 Ch. klippel  -  ck@atelier-klippel.de / c.klippel@gmx.de
 *
 * This code is released under the terms of the GPL, version 2 or newer.
 * See the file COPYING for more information about the license.
 *
 * Changelog:
 *
 * v00.01: - Initial version
 *
 */

#include "rfsupply.h"

#pragma udata access _RENCODER_DATA 
static near signed short encoder_val;
static near unsigned char state_encoder;
static near unsigned char old_state_encoder;
static near unsigned char temp_encoder;
static near unsigned char encoder_cnt;

static near unsigned char button_cnt;
static near unsigned char old_k, cur_k;
static near unsigned char button_sample;
static near unsigned char button_state;
static near unsigned char button;
#pragma udata

static unsigned short enctab[8] =
{
    1000,
     100,
      10,
       5,
       5,
       1,
       1,
       1
};

void encoder_init(void)
{
    logger_print_start_msg(S_ROTARY_ENCODER);

    state_encoder = 0;
    old_state_encoder = state_encoder;
    encoder_val = 0;
    process_encoder();
    encoder_val = 0;
    encoder_cnt = 0;

    button_state = 0;
    button = 0;
    button_sample = 100;
    old_k = 0;

    T0CON = 0b01000010;
    TMR0H = 0xFF;
    TMR0L = 0x00;
    INTCON2bits.TMR0IP = 0;
    INTCONbits.TMR0IF = 0;
    INTCONbits.TMR0IE = 1;
    T0CONbits.TMR0ON = 1;
}

signed short encoder_get(void)
{
    static signed short res;

    INTCONbits.TMR0IE = 0;
    res = encoder_val;
    INTCONbits.TMR0IE = 1;

    return(res);
}

void encoder_reset(void)
{
    INTCONbits.TMR0IE = 0;
    encoder_val = 0;
    INTCONbits.TMR0IE = 1;
}

unsigned char encoder_get_button(void)
{
    static unsigned char tval;

    INTCONbits.TMR0IE = 0;
    if((button_state == BSTATE_DONE) || (button_state == BSTATE_LONGPUSHED))
    {
        tval = button;
    }
    else
    {
        tval = BUTTON_IDLE;
    }
    INTCONbits.TMR0IE = 1;

    return(tval);
}

void encoder_reset_button(void)
{
    INTCONbits.TMR0IE = 0;
    if((button_state == BSTATE_DONE) && (ENC1_K == 1))
    {
        button = 0;
        button_state = 0;
        button_sample = 0;
        button_cnt = 0;
    }
    INTCONbits.TMR0IE = 1;
}

void encoder_clear_button(void)
{
    INTCONbits.TMR0IE = 0;

    button = BUTTON_CLEARED;
    button_sample = 0;
    button_cnt = 0;

    INTCONbits.TMR0IE = 1;
}

void encoder_reset_all(void)
{
    INTCONbits.TMR0IE = 0;

    encoder_val = 0;

    if((button_state == BSTATE_DONE) && (ENC1_K == 1))
    {
        button = 0;
        button_state = 0;
        button_sample = 0;
        button_cnt = 0;
    }

    INTCONbits.TMR0IE = 1;
}

void process_encoder(void)
{
    // handle the rotary encoder

    state_encoder = 0;
    if(ENC1_A)
        state_encoder |= 0x02;
    if(ENC1_B)
        state_encoder |= 0x01;

    if(state_encoder != old_state_encoder)
    {
        temp_encoder = old_state_encoder;
        temp_encoder <<= 2;
        temp_encoder |= state_encoder;

        switch(temp_encoder)
        {
            case 0x01:
            case 0x0E:
                encoder_cnt >>= 5;
                encoder_val += enctab[encoder_cnt];
                if(encoder_val > 9999)
                {
                    encoder_val = 9999;
                }

                encoder_cnt = 0;

                break;

            case 0x04:
            case 0x0B:
                encoder_cnt >>= 5;
                encoder_val -= enctab[encoder_cnt];

                if(encoder_val < -9999)
                {
                    encoder_val = -9999;
                }

                encoder_cnt = 0;
                
                break;

            default:
                break;
        }

        old_state_encoder = state_encoder;
    }

    if(encoder_cnt < 0xFF)
    {
        encoder_cnt++;
    }

    
    // handle the button

    cur_k = ENC1_K;

    if(cur_k != old_k)
    {
        button_sample = 0;
        old_k = cur_k;
    }
    else
    {
    
        button_sample++;

        if(button_sample == 150)
        {
            button_sample = 0;
            switch(button_state)
            {
                case BSTATE_IDLE:
                    if(cur_k == 0)
                    {
                        button_state = BSTATE_FIRSTPUSH;
                        button_cnt = 0;
                    }
                    break;

                case BSTATE_FIRSTPUSH:
                    if(cur_k == 0)
                    {
                        if(button_cnt >= BUTTON_TIME_LONG)
                        {
                            button_state = BSTATE_LONGPUSHED;
                            button = BUTTON_LONGPUSH;
                        }
                    }
                    else
                    {
                        button_state = BSTATE_FIRSTRELEASE;
                        button_cnt = 0;
                    }
                    break;
                case BSTATE_LONGPUSHED:
                    if(cur_k == 1)
                    {
                        button_state = BSTATE_DONE;
                    }
                    break;

                case BSTATE_FIRSTRELEASE:
                    if(cur_k == 1)
                    {
                        if(button_cnt >= BUTTON_TIME_SHORT)
                        {
                            button_state = BSTATE_DONE;
                            button = BUTTON_CLICKED;
                        }
                    }
                    else
                    {
                        button_state = BSTATE_SECONDPUSH;
                        button_cnt = 0;
                    }
                    break;

                case BSTATE_SECONDPUSH:
                    if(cur_k == 0)
                    {
                        if(button_cnt >= BUTTON_TIME_LONG)
                        {
                            button_state = BSTATE_DONE;
                            button = BUTTON_CLICKPUSH;
                        }
                    }
                    else
                    {
                        button_state = BSTATE_SECONDRELEASE;
                        button_cnt = 0;
                    }
                    break;

                case BSTATE_SECONDRELEASE:
                    if(cur_k == 1)
                    {
                        button_state = BSTATE_DONE;
                        button = BUTTON_DOUBLECLICKED;
                    }
                    break;

                case BSTATE_DONE:
                    button_cnt = 0;
                    button_sample = 0;
                    old_k = 0xA5;
                    break;
            }

            if(button_cnt <= BUTTON_TIME_LONG)
            {
                button_cnt++;
            }
        }
    }
}

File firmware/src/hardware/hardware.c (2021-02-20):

/*
 * (c) 2013 Ch. klippel  -  ck@atelier-klippel.de / c.klippel@gmx.de
 *
 * This code is released under the terms of the GPL, version 2 or newer.
 * See the file COPYING for more information about the license.
 *
 * Changelog:
 *
 * v00.01: - Initial version
 *
 */

#include "rfsupply.h"

static unsigned long cnt1;

void hardware_init(void)
{
	// configure oscillator, internal 8MHz, x4 PLL
	OSCCON = 0b11110000;

        while(OSCCONbits.IOFS == 0)
        {
            _asm NOP _endasm;
        }

	OSCTUNE = 0b01000000;
/*
        while(OSCCONbits.OSTS == 0)
        {
            _asm NOP _endasm;
        }
*/
        ADCON0	= 0b00000000;
	ADCON1	= 0b00001100;
//	ADCON2	= 0b00001001;

	SSPCON1 = 0b00000000;
	CMCON	= 0b00000111;
	CVRCON	= 0x00000000;
	T0CON	= 0b00000000;

	INTCON2bits.RBPU = 0;

	LATA = CFG_LATA;
	LATC = CFG_LATC;
	LATB = CFG_LATB;

        TRISA = CFG_TRISA;
	TRISB = CFG_TRISB;
	TRISC = CFG_TRISC;

        CCPR2L = 0;
}

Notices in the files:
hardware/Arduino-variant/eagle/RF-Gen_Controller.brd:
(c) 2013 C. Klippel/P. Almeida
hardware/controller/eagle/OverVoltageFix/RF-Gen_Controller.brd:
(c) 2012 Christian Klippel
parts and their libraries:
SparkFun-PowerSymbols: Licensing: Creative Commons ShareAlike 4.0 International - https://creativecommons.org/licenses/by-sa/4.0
